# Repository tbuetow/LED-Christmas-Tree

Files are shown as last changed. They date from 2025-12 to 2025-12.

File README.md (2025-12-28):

# 🎄RGB LED Christmas Trees! <!-- omit in toc -->

- [How We Made These](#how-we-made-these)
  - [3D Printed Parts](#3d-printed-parts)
    - [Base](#base)
    - [Trees](#trees)
    - [PCB Fixture](#pcb-fixture)
  - [Circuit Boards](#circuit-boards)
  - [Software](#software)
  - [Putting it all together](#putting-it-all-together)
- [Building your own effects](#building-your-own-effects)
  - [Prerequisites](#prerequisites)
  - [VSCode / PlatformIO](#vscode--platformio)
  - [Writing effects](#writing-effects)

Each year, I make a small holiday bauble for teachers, family, and friends. Usually my wife and I come up with an idea around Thanksgiving and then panic for three weeks to deliver something by the last day of school for the holidays.

This year we chose to revisit something we made 7 years ago, but improve on it, building on some of my more recent projects with addressable RGB LEDs and better tools like my multiple extruder 3D printer and solder reflow oven.

The concept is a clear thin 3D printed tree on top of a 3D printed base that powers LEDs inside of it. 7 years ago, this was a pair of AA batteries, a single discrete color changing LED, and a power switch. You could also run it off of a 5V supply via micro-USB. Times have changed now! I had a few simple improvements I wanted to make.

- USB-C with proper support for all USB-C power supplies. I chose to drop batteries just due to cost.
- A ring of addressable RGB LEDs instead of a single unmodifiable color changing LED.
- The ability to change the LED color effects, and provide many included options.
- Multiple color printing to make it more beautiful.
- Under $10 and very easy to manufacture, since we want to make 30-40 of these.
- Document the process to share with others and allow those who are inclined to write their own color effects.

# How We Made These
## 3D Printed Parts
### Base
I designed the base and all other fixtures and accessories (except for the trees) in Autodesk Fusion.

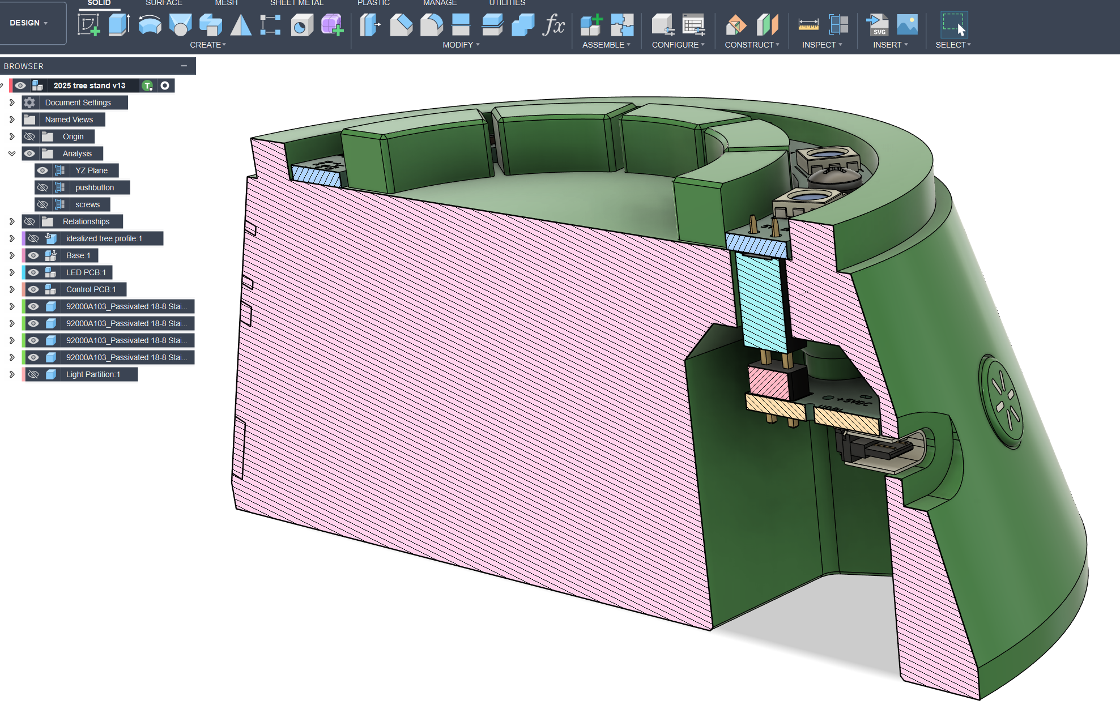
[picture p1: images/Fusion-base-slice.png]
Fusion screenshot


You can download the full model from my [Fusion account](https://a360.co/4piaKZ3) if you want to make modifications yourself. Fusion is free for personal use; get it [here](https://www.autodesk.com/products/fusion-360/overview).

The most likely thing you will want to modify is the embedded text. Just edit the text sketch on the Base component. I've removed the bottom row for the shared model. If you want to add one, add a text to the lower curved line. You will then want to edit the emboss and boundary fill operations immediately after the text in order to ensure the new text is properly embossed.

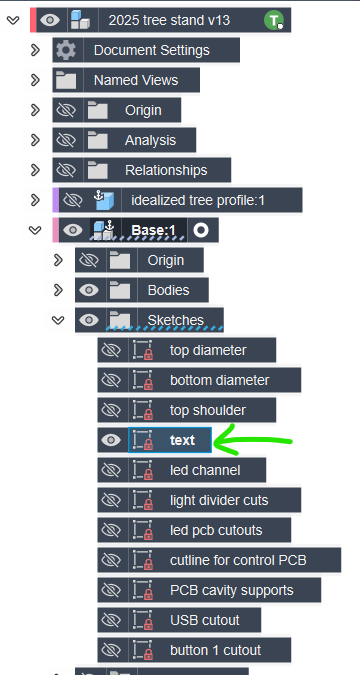
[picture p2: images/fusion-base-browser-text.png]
Fusion Browser Tree View, highlighting a sketch called text


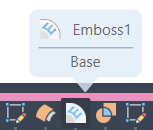
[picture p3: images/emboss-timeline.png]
Fusion timeline, highlighting the text sketch and the emboss and boundary fill operations


Printing was done on my Prusa XL and Core One.
I started by testing color combinations:

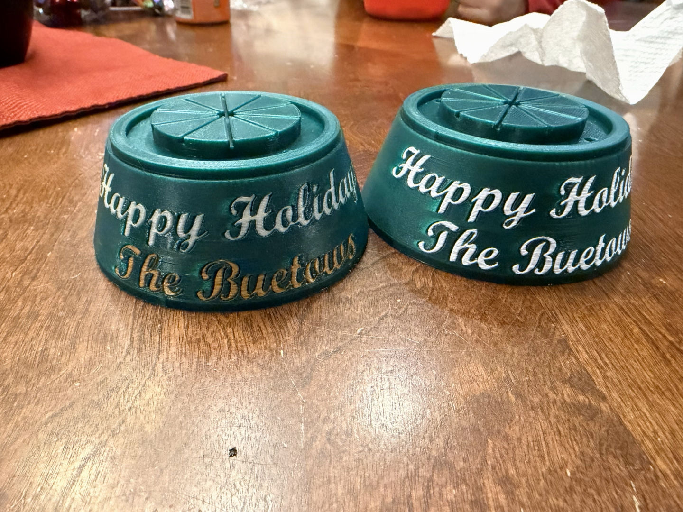
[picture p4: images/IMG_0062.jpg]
Tree base in green with text colors for text


Once done, I was able to begin producing them multiples at a time:

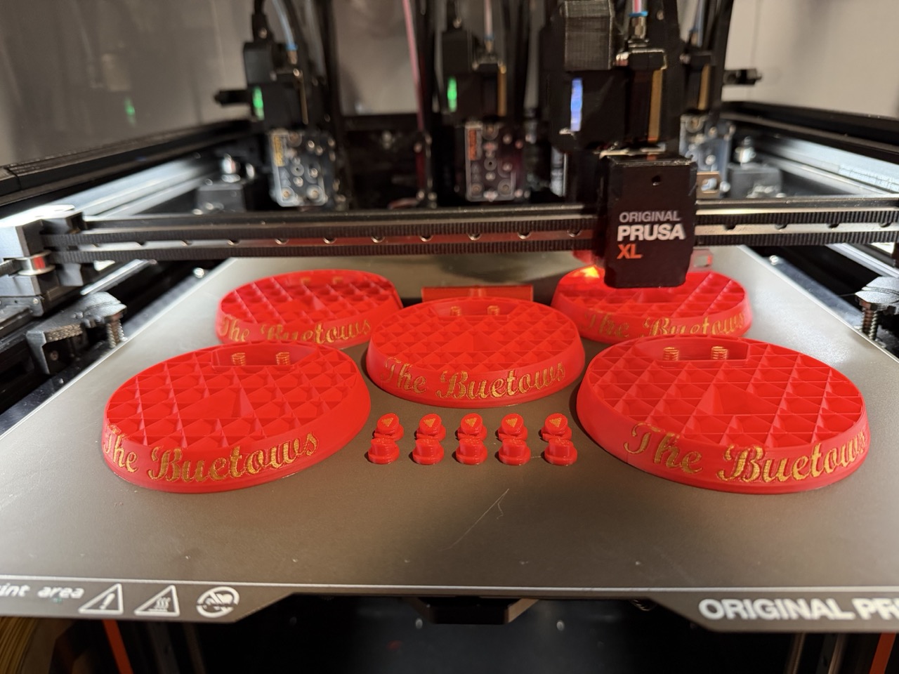
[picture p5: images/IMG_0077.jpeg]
Tree base printing in progress


The light dividers and trees were printed on the Core One. Lots of time starting the next print!

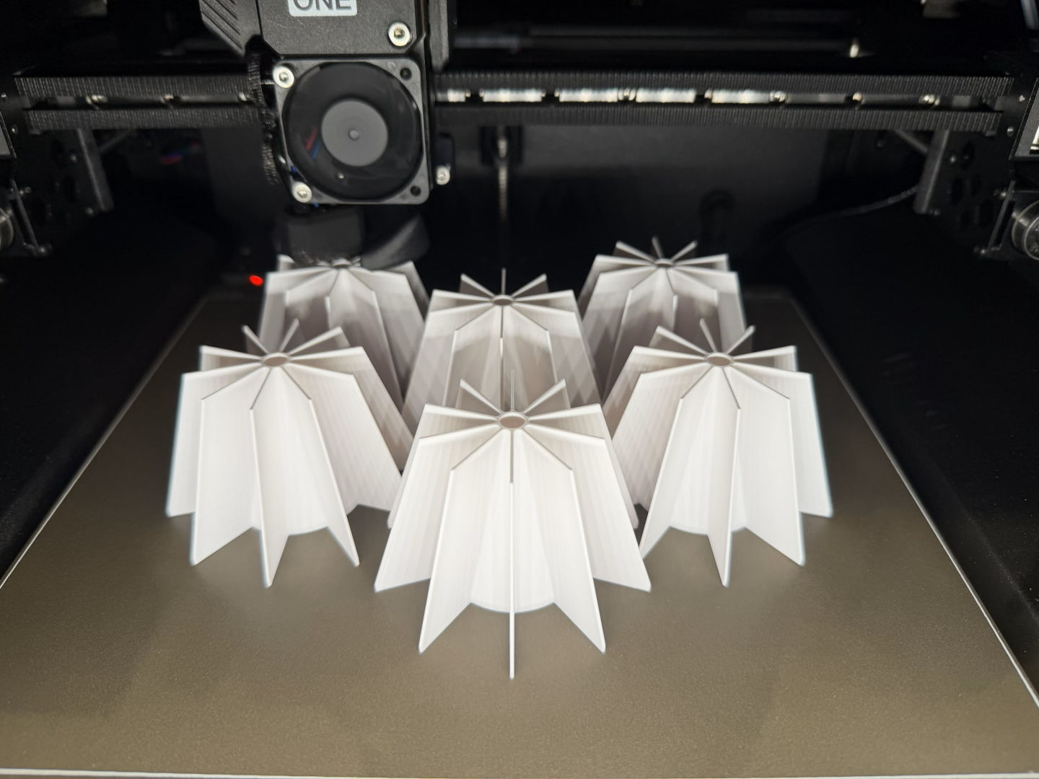
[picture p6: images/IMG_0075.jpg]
Plastic dividers printing


### Trees
I used tree designs that would print well in vase mode since I wanted them to be transparent. See [Trees](hw/Trees/) for more information.

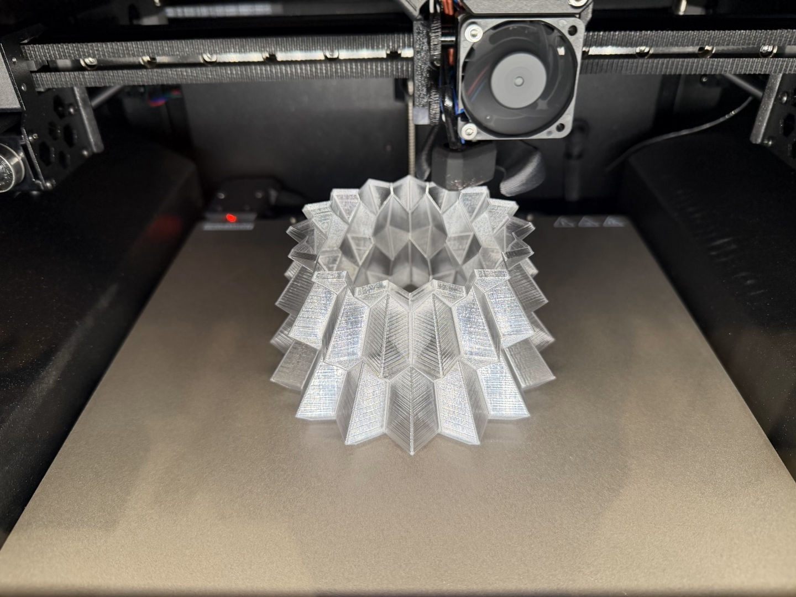
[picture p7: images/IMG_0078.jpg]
Clear tree printing in vase mode


Eventually the trees multiplied. Storing things became a challenge!

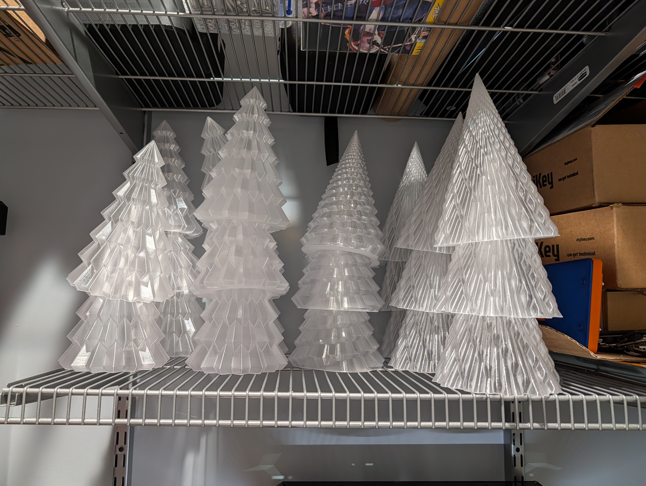
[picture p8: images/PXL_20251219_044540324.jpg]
Lots of printed trees


### PCB Fixture
I designed and printed a fixture to help with soldering as well, available in [Fixtures](/hw/Fixtures/). The fixture was printed in carbon-fiber reinforced PETG, to help the print maintain flatness. Any similar material, maybe even plain PLA, may be fine. The holes on the left are for M4 heat set inserts, used to hold the clamp in place.

<!-- Insert Fixture Picture here -->

## Circuit Boards
The circuit boards were designed in KiCAD. Thanks to the power of modern microprocessors and addressable LEDs, the circuit is quite simple.
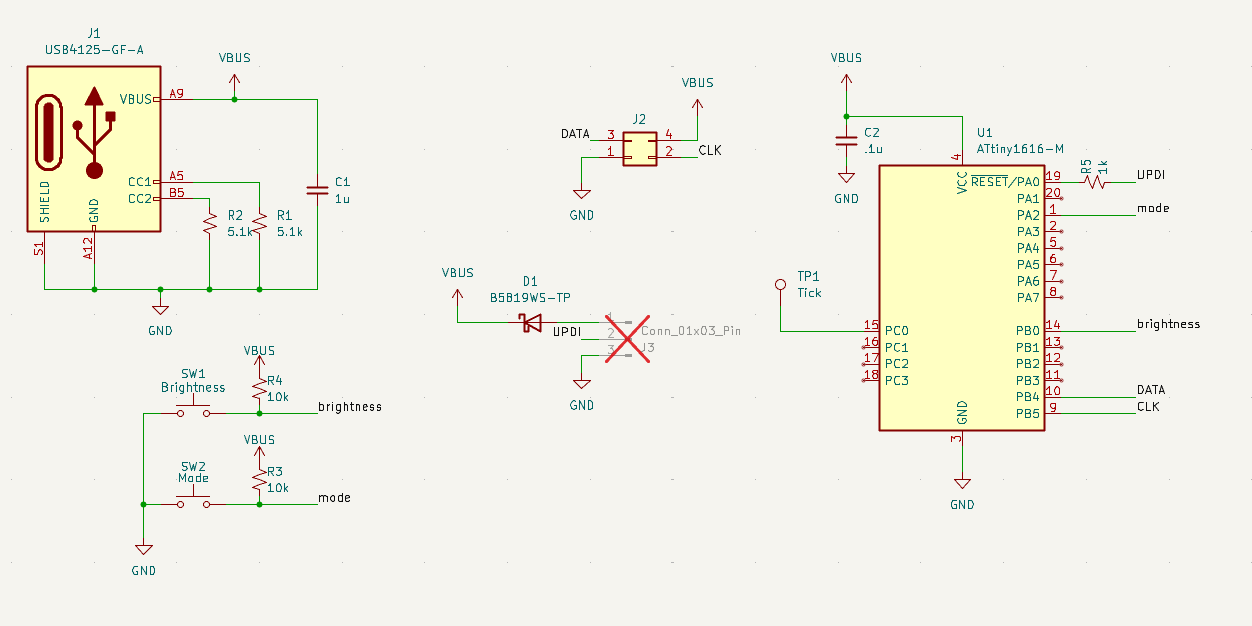
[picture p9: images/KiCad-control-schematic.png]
KiCad Electrical Schematic


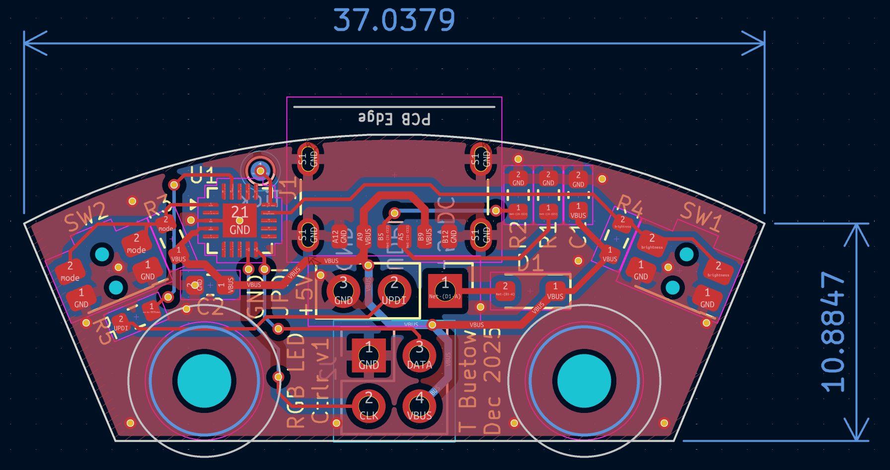
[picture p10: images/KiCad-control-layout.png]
KiCad Electrical Layout


The control board is **very** small, just 37mm (under 1.5") across. This is in part because I can get the new(er) Microchip ATTiny1616 in a VQFN package. These are ordered as bare PCBs and I use solder paste and stencils to set components and then reflow them in my solder oven. Hand soldering these would not be possible! The microprocessor has a 0.4mm (1/64") pitch, which is really tiny! It would be better to switch to slightly larger components and change the microprocessor out for one in a SOIC package or similar if you don't have a reflow oven.

However, I do have one!

You start by spreading solder paste over a thin steel stencil onto the PCB.
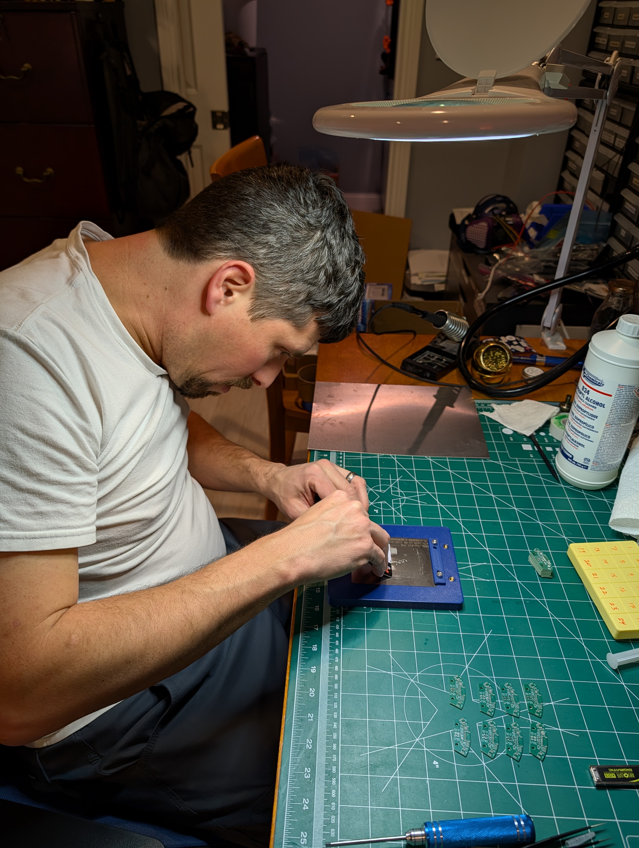
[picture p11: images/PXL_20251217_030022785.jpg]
Applying solder paste to a stencil on a fixture


Then components are carefully placed onto the board, sitting on the solder paste.
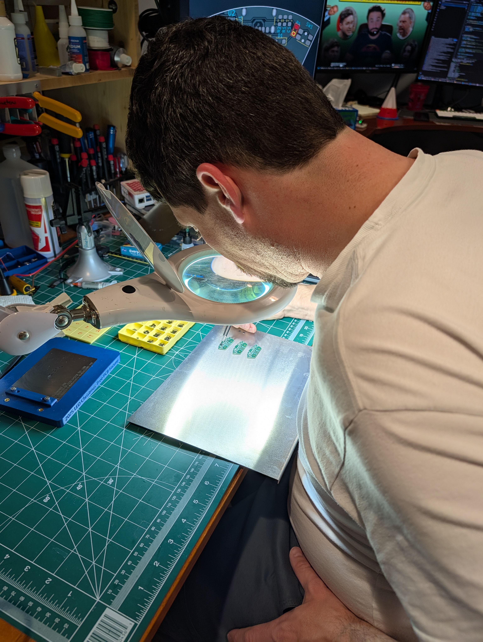
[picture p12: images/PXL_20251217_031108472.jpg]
Looking through a magnifier while placing components on a PCB.


Then they are baked in my reflow oven, converted from a cheap toaster oven. 30 seconds at 473F should do nicely!
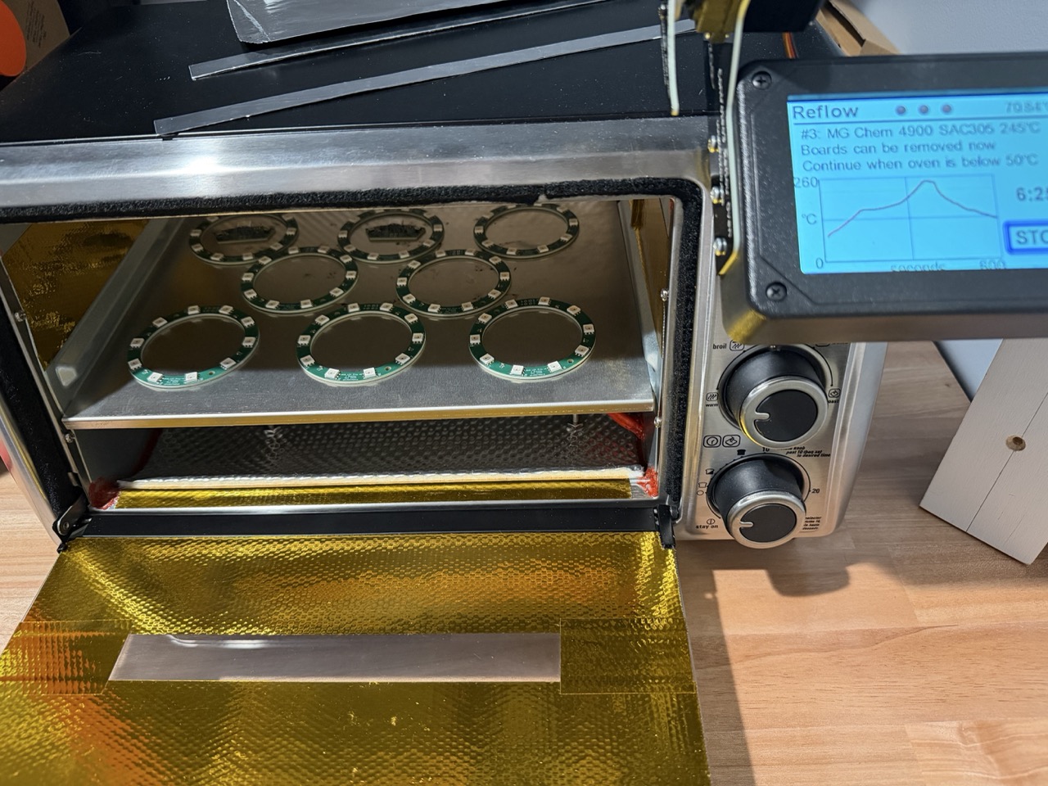
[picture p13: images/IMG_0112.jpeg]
Circuit boards fresh from the reflow oven


Once done, the fixture was used again to do the hand soldering part to add the header pins to connect the two boards together.
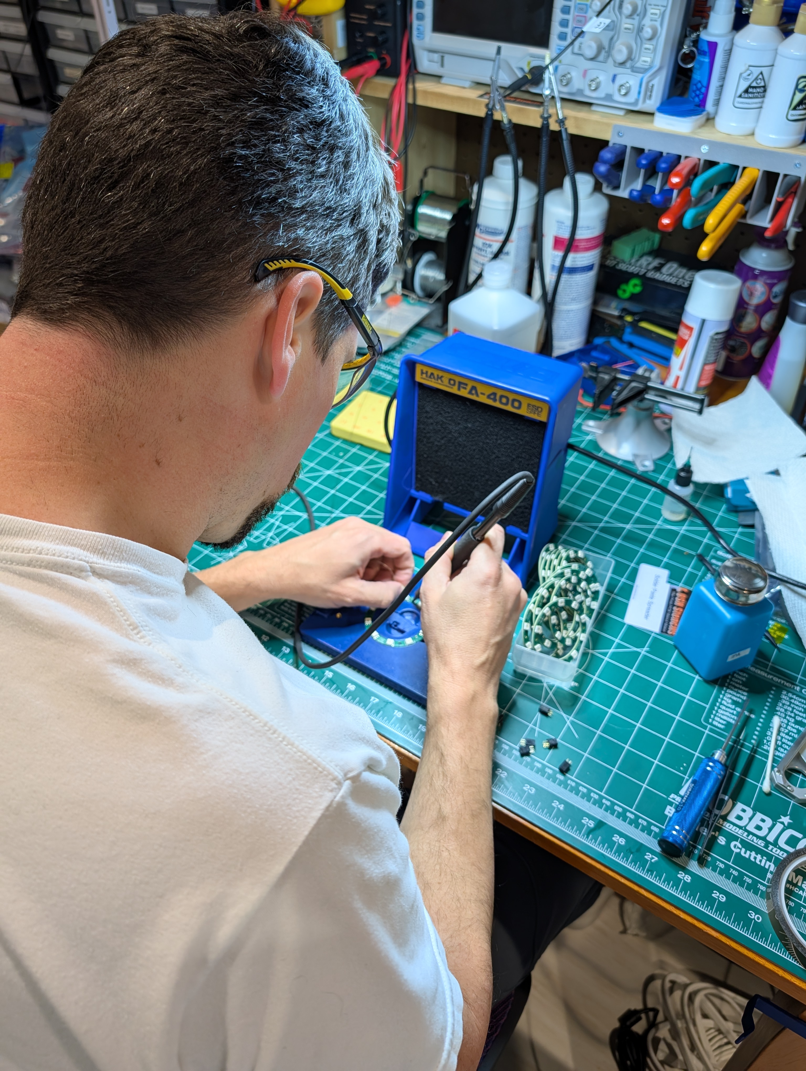
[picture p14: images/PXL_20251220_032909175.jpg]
Hand soldering parts onto a PCB


## Software
I used PlatformIO in VSCode as my IDE to program the microcontrollers. This works well and makes it easy to import the Arduino framework and FastLED library for quick access to easy-to-use functions and tools.

The bulk of the code came from another project I made where I had LED name plates that were edge-lit with RGB LEDs. I just added a few additional effects. [main.cpp](src/main.cpp) is where the effect implementations live and is available in the [src](src/) folder. Also there is [config.h](src/config.h) that contains all the "user" changeable parameters that I broke out. This made it easy to tune the effects to get them to look the way I wanted.

One of the new techniques I made is called Holiday Noise. It uses Perlin Noise to shift between red, green, and white colors. You can learn more about the 2D Perlin Noise in FastLED (one of the dimensions is time!) the same way I did by watching [this YouTube video by Scott Marley](https://youtu.be/7Dhh0IMSI4Q?t=266).

## Putting it all together
The base is designed to print with only minimal support (see the 3mf core one or XL files in [Base Hardware](/hw/Base/)).

Step 1 was to place the buttons and the control board in the bottom. The base was designed to allow it to slide into position, locking the buttons in place. M2.5 screws were used to hold the PCB in place.
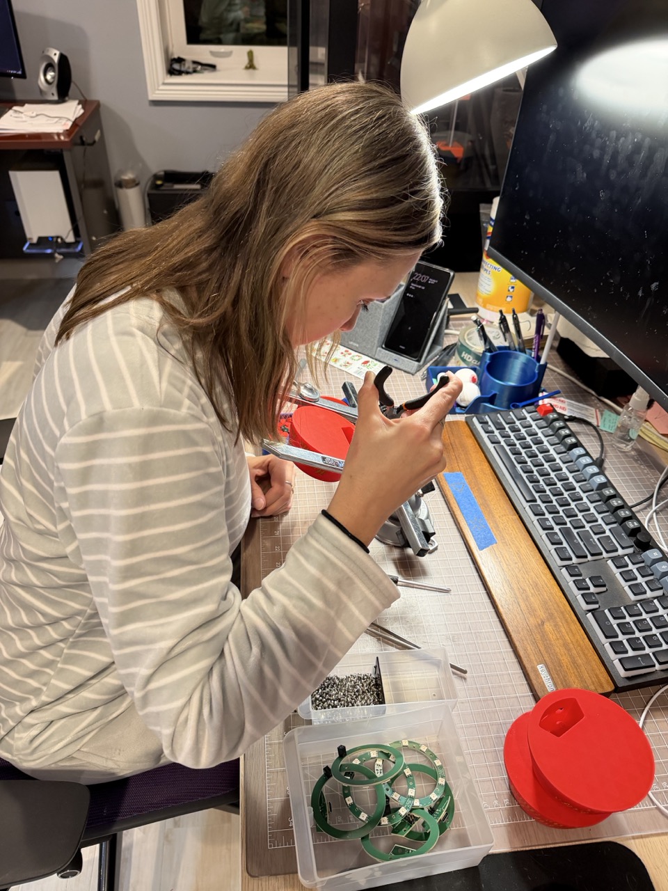
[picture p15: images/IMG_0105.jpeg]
Installing buttons and control board into base


Then the LED ring simply installed on the top with two more screws. The header pins lined up precisely to provide the electrical connections between the two boards.
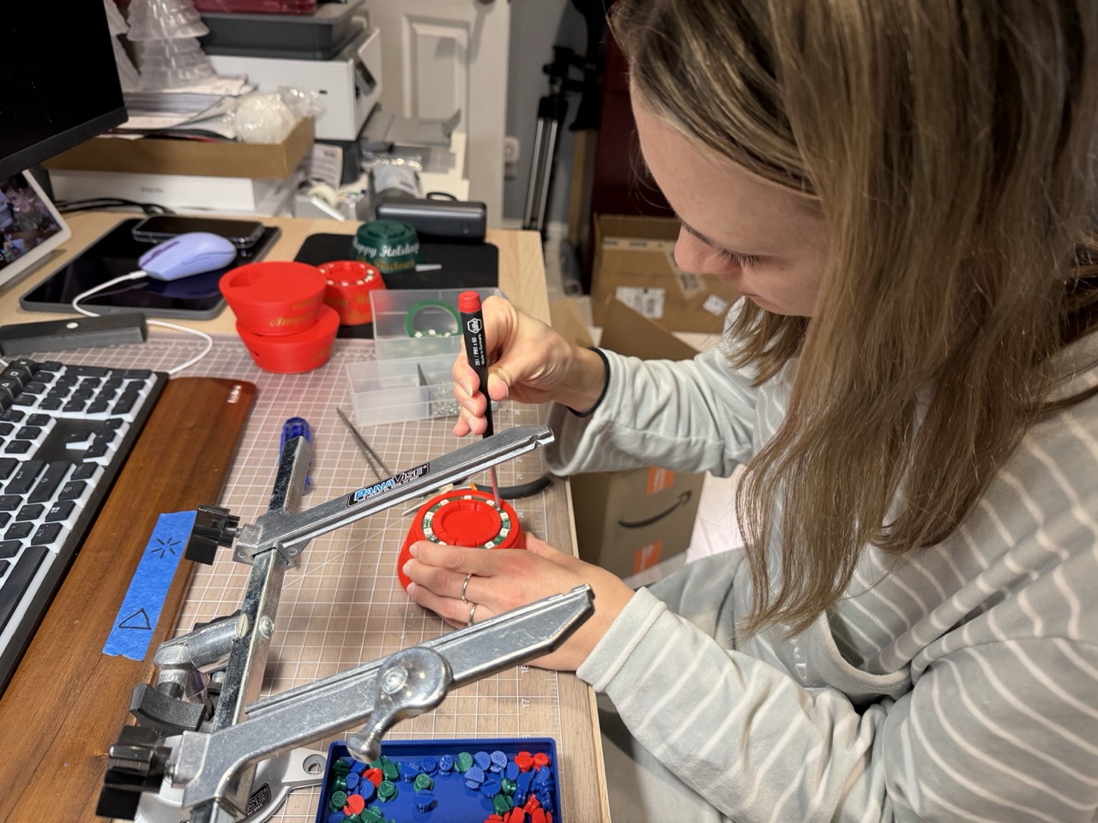
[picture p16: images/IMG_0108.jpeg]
Screwing LED PCB onto base


Finished!
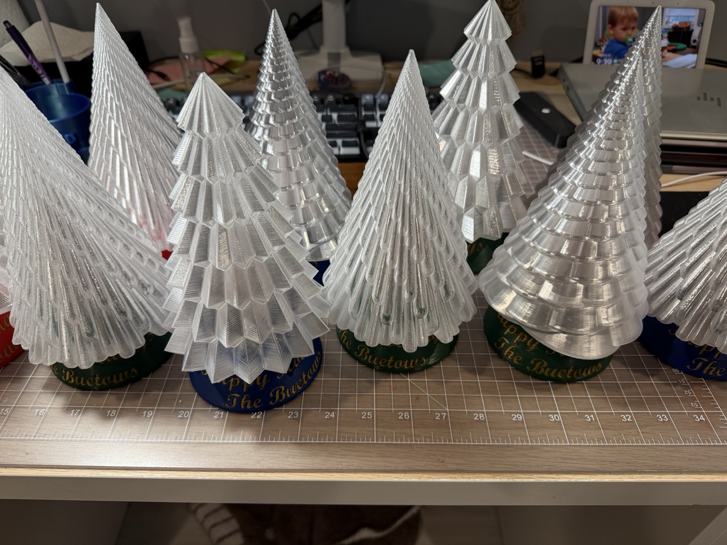
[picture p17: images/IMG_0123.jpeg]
Large collection of completed trees


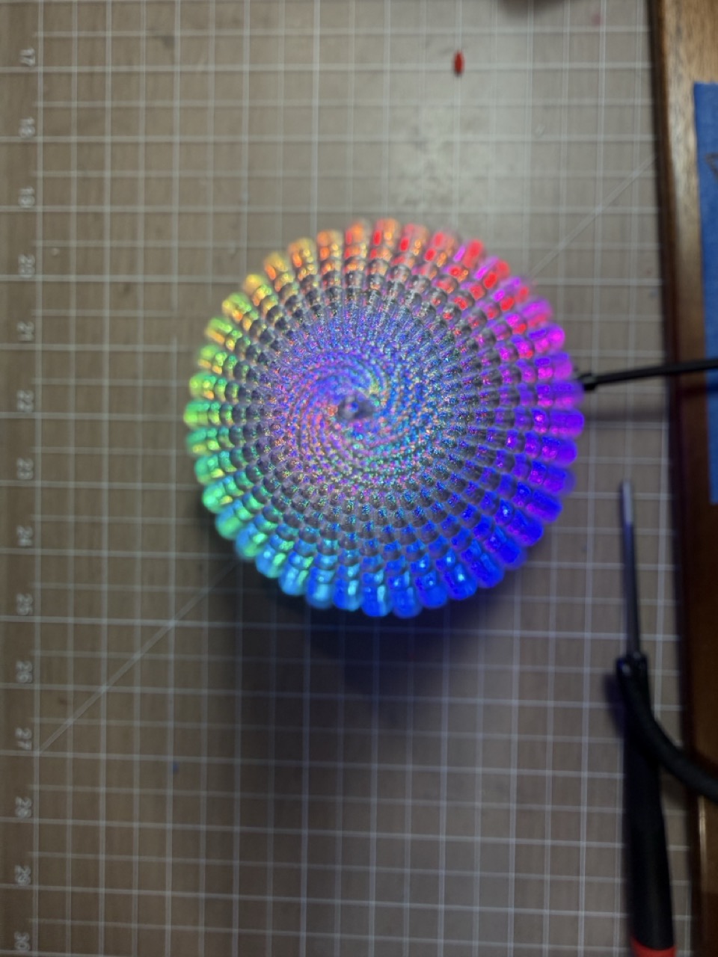
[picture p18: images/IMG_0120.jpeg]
Top down tree with rainbow effect


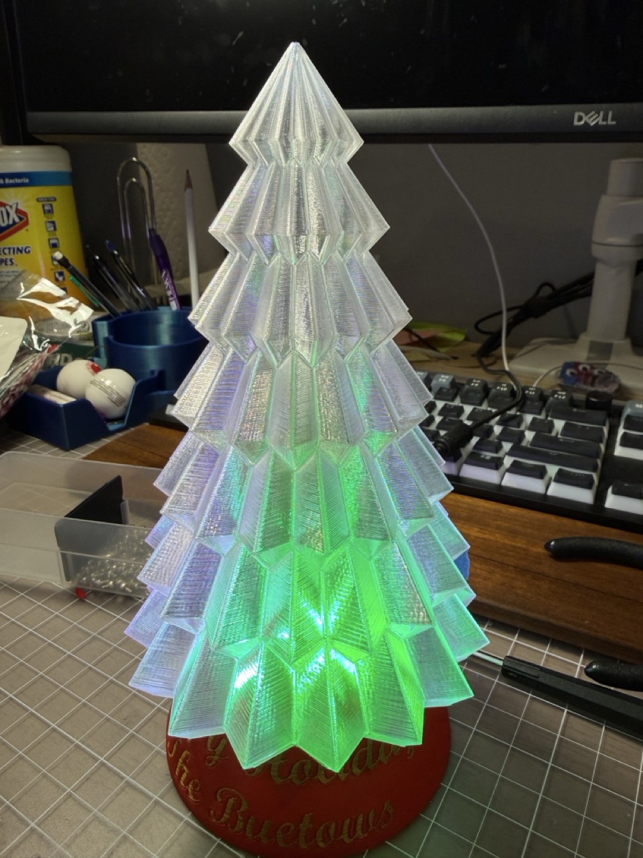
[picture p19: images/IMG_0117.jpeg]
Tree light up with green carousel effect


# Building your own effects
## Prerequisites
- **Programmer:** You will need a UPDI programmer. You can make one from a USB to serial adapter by just connecting USB Serial RX to the UPDI pin, and then the USB Serial TX to RX with a 1kΩ Resistor. Or you can buy something cheap like the [Adafruit UPDI Friend](https://www.adafruit.com/product/5879) or the High Voltage version too.

- **Jumper wires:** If I installed the 3 male header pins on your board, you will need to adapt the Programmer to 3 0.1" female connectors. The Adafruit one will give you 3 male header pins, so you will need 3 female to female jumpers. Grab [these](https://www.adafruit.com/product/1950) from Adafruit if you are already buying the UPDI Friend, or they are also in [this pack](https://www.amazon.com/Elegoo-EL-CP-004-Multicolored-Breadboard-arduino/dp/B01EV70C78) from Amazon. 

  Programming without the male header is still possible, I just press the programming pins into the holes and push them sideways to ensure electrical contact.

- **VSCode:** You will need an Integrated Development Environment. I use [VSCode](https://code.visualstudio.com/). Within VSCode, you will need the PlatformIO extension. Go to the Extensions tab and search for it within VSCode or grab it from the [extensions marketplace](https://marketplace.visualstudio.com/items?itemName=platformio.platformio-ide).

- **Git:** You probably want to get the [git version control system](https://git-scm.com/) to make it easy to get access to the code. This step is technically optional, but will allow you to undo changes you make at any time.

## VSCode / PlatformIO
1) Install the PlatformIO extension in VSCode. After it finishes, reload VSCode so it can add toolchains the first time you open the project.
1) Clone or download this repo. If you have git, use `git clone` from a terminal. Otherwise use the green "Code" button on GitHub to download a zip, then unzip it somewhere easy to find.
1) In VSCode, go to `File -> Open Folder...` and pick the project root. PlatformIO should notice `platformio.ini` and prompt to install anything it needs—let it run to completion.
1) In the left sidebar, open `platformio.ini` to confirm the `ATtiny1616` environment is selected. Click `src/main.cpp` to browse the effects code and `src/config.h` to tweak tunable values.
1) Hook up your UPDI programmer: UPDI to the single UPDI pin, GND to GND, and 5V to VCC on the control board. I keep the base on its back so the pins are easy to reach.
1) Click the PlatformIO checkmark (Build) to make sure everything compiles, then use the right-facing arrow (Upload using Programmer) to flash the board.

## Writing effects
To write your own effects, you'll need to touch at least two files, ideally 3.

The effects are implemented in [main.cpp](/src/main.cpp). That is where you will do the bulk of the work. Add a case statement to the switch conditional in the loop() function. 

However, the system won't know your effect exists until you add it to the list of states. Go to the [state.h](/src/state.h) file and add it to the Mode class. This class defines the order the effects rotate through when you push the next button on the base.

If you wish to make tuneable variables, it's best practice to add them in [config.h](/src/config.h) but I won't judge you if you just hard code them all in your implementation code.

My effects make use of the `EVERY_N_MILLIS()` timer capabilities in FastLED extensively. This avoids a whole bunch of timer checking code since the people who wrote FastLED are way better at this stuff than I am.

Hopefully that's enough to get you started on your own. Don't be afraid to feed main.cpp to a chatbot and ask it to help you add new effects in the right format. It's a great way to experiment at first. Have fun!

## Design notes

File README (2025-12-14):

# 🎄RGB LED Christmas Trees!

Each year, I make a small holiday bauble for teachers, family, and friends. Usually my wife and I come up with an idea around Thanksgiving and then panic for three weeks to deliver something by the last day of school for the holidays.

This year we chose to revisit something we made 7 years ago, but improve on it, building on some of my more recent projects with addressable RGB LEDs and better tools like my multiple extruder 3D printer and solder reflow oven.

The concept is a clear thin 3D printed tree on top of a 3D printed base that powers LEDs inside of it. 7 years ago, this was a pair of AA batteries, a single discrete color changing LED, and a power switch. You could also run it off of a 5V supply via micro-USB. Times have changed now! I had a few simple improvements I wanted to make.

- USB-C with proper support for all USB-C power supplies. I chose to drop batteries just due to cost.
- A ring of addressable RGB LEDs instead of a single unmodifiable color changing LED.
- The ability to change the LED color effects, and provide many included options.
- Multiple color printing to make it more beautiful.
- Under $10 and very easy to manufacture, since we want to make 30-40 of these.
- Document the process to share with others and allow those who are inclined to write their one color effects.

## 3D Printed Parts
I designed the base and all other fixtures and accessories, except for the trees in Autodesk Fusion.
Fusion screenshot

Printing was done on my Prusa XL and Core One.
I started by testing color combinations:
Tree base in green with text colors for text

Once done, I was able to begin producing them multiples at a time:
Tree base printing in progress

The light dividers and trees were printed on the Core One. Lots of time starting the next print!
Clear tree printing in vase mode
Plastic dividers printing

## Circuit Boards
The circuit boards were designed in KiCAD. Thanks to the power of modern microprocessors and addressable LEDs, the circuit is quite simple.
KiCad Electrical Schematic
KiCad Electrical Layout

The control board is **very** small, just 37mm (under 1.5") across. This is in part because I can get the new(er) Microchip ATTiny1616 in a QFN packaged. These are ordered as bare PCBs and I use solder paste and stencils to set components and then reflow them in my solder oven. I would not recommend hand soldering these unless you are very skilled. It would be better to switch to slightly larger components and change the microprocessor out for one in a SOIC package or similar.

<Insert solder oven photo here>

## Software
I used PlatformIO in VSCode as my IDE to program the microcontrollers. This works well and makes it easy to import the Arduino framework and FastLED library for quick access to easy-to-use functions and tools.

The bulk of the code came from another project I made where I had LED name plates that were edge-lit with RGB LEDs. I just added a few additional effects. [main.cpp](src/main.cpp) is available in the [src](src/) folder.

# Building your own effects
## Prerequisites

## VSCode / PlatformIO

## Writing effects

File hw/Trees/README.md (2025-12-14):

# Vase Trees
A Selection of trees that I liked to print in vase mode and put on top of the LED Bases.

The spiral trees are courtesy of [Triple G Workshop](https://www.printables.com/model/655419-ultimate-vase-mode-christmas-tree-collection/files).

The pointy tree is courtesy of [SASSy Design](https://www.printables.com/model/684498-sassy-christmas-tree-vase-mode-geometrical-design).

## Project 3MF files
The 3MF files here are preconfigured for printing, including the hole to fit over the LED base, as described below.

All trees in the project have some form of license or copyright that I do not control unless stated otherwise. Individual trees have their associated licenses detailed in their respective folders.

Unfortunately, some of these licenses do not allow me to host copies or even derivative works, so they are not included here. Please see the attribution documents and links above to obtain them.

## How to Slice
### Import model
Bring the model into your slicer and resize it to be 120mm in diameter (set X and Y to be the same) and 180mm in height. You may need to unlock sizing constraints

### Add hole to fit over LED Base
Add a negative cylinder shape to the tree in your slicer.

Make it 75.1mm in diameter and 1mm tall.

Make sure it is placed on the bed and centered with reference to the tree model

### Slicer settings
Set the slicer to vase mode

The gcode preview should show an open hole at the bottom, with an inner wall that is 1mm high.

### Optional point fix
These trees will all end up with very sharp tips. I recommend using your slicer to cut off the top 2mm.

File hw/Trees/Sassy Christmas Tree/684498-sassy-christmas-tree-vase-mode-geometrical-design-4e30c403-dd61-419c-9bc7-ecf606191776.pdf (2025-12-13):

# Sassy Christmas Tree - Vase mode -

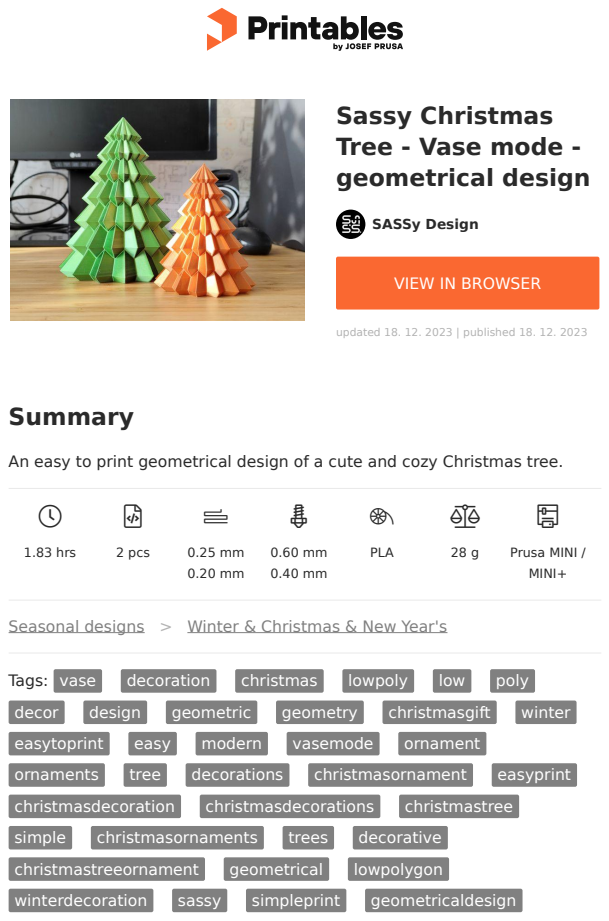
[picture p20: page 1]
1.83 hrs; 2 pcs; PLA; Prusa MINI /; MINI+; Summary; Seasonal designs; Winter & Christmas & New Year's; Tags: vase; decoration; christmas; lowpoly; low; poly; decor; design; geometric; geometry; christmasgift; winter; easytoprint; easy; modern; vasemode; ornament; ornaments; tree; decorations; christmasornament; easyprint; christmasdecoration; christmasdecorations; christmastree; simple; christmasornaments; trees; decorative; christmastreeornament; geometrical; lowpolygon; winterdecoration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

VIEW IN BROWSER (https://printables.com/model/684498-sassy-christmas-tree-vase-mode-geometrical-design)

An easy to print geometrical design of a cute and cozy Christmas tree.

# Model files

# Print files

moderndesign | geometricdesign | 2023 | vasemodeprinting
sassydesign | winterdecorations

An easy to print geometrical design of a cute and cozy Christmas tree.

### Print information:

Recommended vase mode or semi-vasemode settings (0% infill, 0 top

layers, 4 or 5 bottom layers, 2 or 3 outer perimeters - for a stronger

print)

Recommended using a lower layer hight (0.15/0.2mm) for better

results in details

Prints very good in any filament

The model is scalable to your liking

Happy printing!

And a Merry Christmas to all of you!

h PLA | k 0.60 mm | f 0.25 mm | 1.83 hrs | 28 g | d Prusa MK4

•

•

•

•

sassy-christmas-tree_vase-mode.stl

sassy-christmas-tree.stl

sassy-christmas-tree__06n_025mm_pla_mk4is_1h50m.gcode

h PLA | k 0.40 mm | f 0.20 mm | 2.23 hrs | 20 g | d Prusa MINI / MINI+

# License

This work is licensed under a Standard Digital File Licence.

Digital files have a strict non-commercial, personal use only license.

You shall not share, sub-license, sell, rent, host, transfer, or distribute in

any way the digital file or 3D printed versions of this object, nor any other

derivative work of this object in its digital or physical format (including

remixes of this object).

You can not host these files on other digital platforms, web stores or cloud

repositories.

The objects may not be used in any way whatsoever in which you charge

money, collect fees.

✖ | No sharing or redistributing in any way of the 3D files or derivatives
✖ | No remixing
✖ | Non-commercial Use (only for personal use) sassy-christmas-tree__04n_02mm_pla_mini_2h14m.gcode

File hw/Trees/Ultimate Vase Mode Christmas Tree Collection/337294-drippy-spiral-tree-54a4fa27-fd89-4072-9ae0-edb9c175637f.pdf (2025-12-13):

## Drippy Spiral Tree

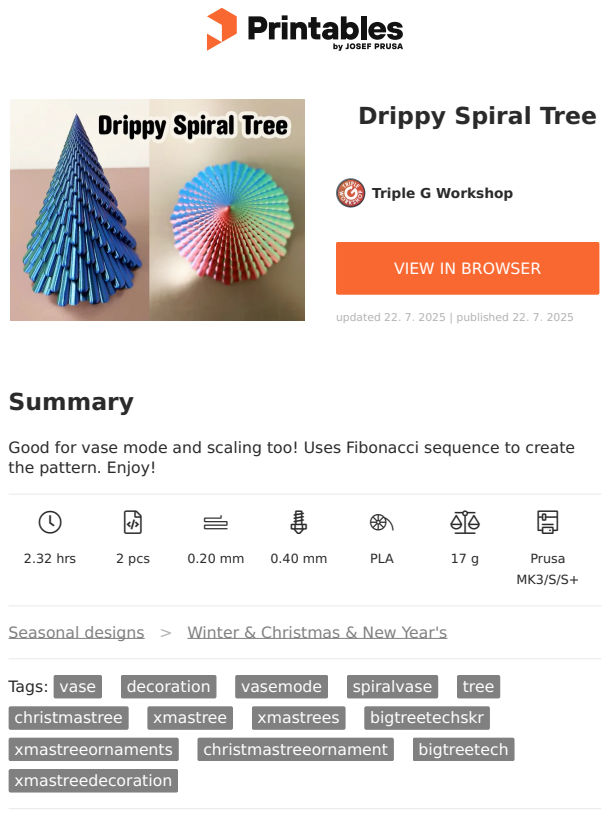
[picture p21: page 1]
2.32 hrs; 2 pcs; PLA; Prusa MK3/S/S+; Summary; Tags:; vase; decoration; vasemode; spiralvase; tree; christmastree; xmastree; xmastrees; bigtreetechskr; xmastreeornaments; christmastreeornament; bigtreetech; xmastreedecoration; Triple G Workshop; updated 22. 7. 2025 | published 22. 7. 2025

VIEW IN BROWSER (https://printables.com/model/337294-drippy-spiral-tree)

Good for vase mode and scaling too! Uses Fibonacci sequence to create
the pattern. Enjoy!

Seasonal designs (https://printables.com/model?categoryId=65) > Winter & Christmas & New Year's (https://printables.com/model?categoryId=70)

## Model files

## Print files

h PLA k 0.40 mm f 0.20 mm 2.32 hrs 17 g d Prusa MK3/S/S+

h PLA k 0.40 mm f 0.20 mm 0.74 hrs 5 g d Prusa MK3/S/S+

## License

This work is licensed under a
Creative Commons (4.0 International License)

Attribution—Noncommercial—Share Alike (http://creativecommons.org/licenses/by-nc-sa/4.0/)

✖ | Sharing without ATTRIBUTION
✔ | Remix Culture allowed
✖ | Commercial Use
✖ | Free Cultural Works
✖ | Meets Open Definition

drippy-spiral-tree.3mf

drippy-spiral-tree.stl

drippy-spiral-tree-solid_02mm_pla_mk3s_2h19m.gcode

drippy-spiral-tree-_vase-mode_-02mm_pla_mk3s_45m.gcode

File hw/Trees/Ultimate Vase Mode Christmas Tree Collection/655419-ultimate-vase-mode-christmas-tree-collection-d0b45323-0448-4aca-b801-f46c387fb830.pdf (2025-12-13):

## ⍋ Ultimate Vase Mode Christmas

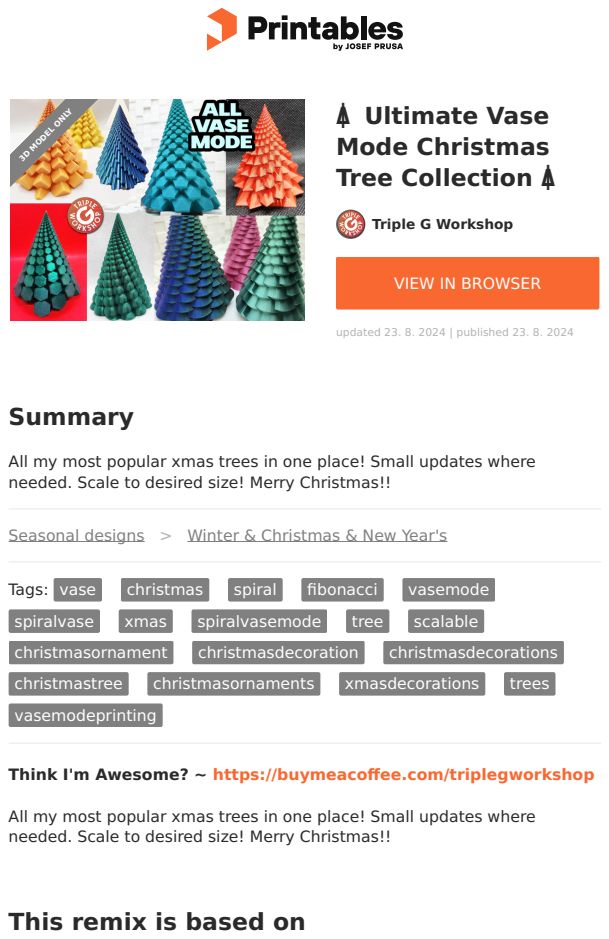
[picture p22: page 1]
Summary; Tags:; vase; christmas; spiral; fibonacci; vasemode; spiralvase; xmas; spiralvasemode; tree; scalable; christmasornament; christmasdecoration; christmasdecorations; christmastree; christmasornaments; xmasdecorations; trees; vasemodeprinting; Triple G Workshop; Tree Collection ⍋; updated 23. 8. 2024 | published 23. 8. 2024; 3D MODEL ONLY

VIEW IN BROWSER (https://printables.com/model/655419-ultimate-vase-mode-christmas-tree-collection)

All my most popular xmas trees in one place! Small updates where
needed. Scale to desired size! Merry Christmas!!

Seasonal designs (https://printables.com/model?categoryId=65) > Winter & Christmas & New Year's (https://printables.com/model?categoryId=70)

Think I'm Awesome? ~ https://buymeacoffee.com/triplegworkshop (https://t.co/ddvOmmeLwR)

This remix is based on

Fibonacci Spiral Trees No Supports (https://printables.com/model/334911-fibonacci-spiral-trees-no-supports) by Triple G Workshop (https://printables.com/@TripleGWorkshop)

⬡ Crystal-mas Tree Vase Mode ⬡ (https://printables.com/model/337015-crystal-mas-tree-vase-mode) by Triple G Workshop (https://printables.com/@TripleGWorkshop)

Sugar Cube Tree ◇ Vase Mode (https://printables.com/model/456678-sugar-cube-tree-vase-mode) by Triple G Workshop (https://printables.com/@TripleGWorkshop)

Fibonacci Spiral Trees ⍋ Vase Mode V2 (https://printables.com/model/632685-fibonacci-spiral-trees-vase-mode-v2) by Triple G Workshop (https://printables.com/@TripleGWorkshop)

⍋ Crystal Tree & Spiral Vase ⍋ (https://printables.com/model/625815-crystal-tree-spiral-vase) by Triple G Workshop (https://printables.com/@TripleGWorkshop)

Tree Full of Stars ✫ Vase Mode (https://printables.com/model/459173-tree-full-of-stars-vase-mode) by Triple G Workshop (https://printables.com/@TripleGWorkshop)

Vase Mode Xmas Tree ☆ (https://printables.com/model/307157-vase-mode-xmas-tree)
by Triple G Workshop (https://printables.com/@TripleGWorkshop)

Drippy Spiral Tree (https://printables.com/model/337294-drippy-spiral-tree)
by Triple G Workshop (https://printables.com/@TripleGWorkshop)

⍟ Tree of Spheres - Solid or vase mode ⍟ (https://printables.com/model/337759-tree-of-spheres-solid-or-vase-mode) by Triple G Workshop (https://printables.com/@TripleGWorkshop)

Xmas Tree Vase Mode Caddy (https://printables.com/model/452819-xmas-tree-vase-mode-caddy)
by Triple G Workshop (https://printables.com/@TripleGWorkshop)

## Model files

- All Models HERE!

ultimate-vase-mode-christmas-tree-collection.3mf

4-sided-fibonacci-spiral-tree.stl

6-sided-fibonacci-spiral-tree.stl

10-sided-fibonacci-spiral-tree.stl

fibonacci-spiral-trees-v2-1.stl

fibonacci-spiral-trees-v2-2.stl

fibonacci-spiral-trees-v2-3.stl

crystal-tree-vase-mode-tall.stl

crystal-mastreevasemode.stl

- this model may have tiny gaps inside the stars, it experimental

## License

This work is licensed under a
Creative Commons (4.0 International License)

Attribution-ShareAlike (http://creativecommons.org/licenses/by-sa/4.0/)

✖ | Sharing without ATTRIBUTION diamond-xmas-tree-vase-mode.stl

tree-of-spheres-vase-mode.stl

sugar-cube-tree-vase-mode.stl

christmas-tree-with-star-vase-mode.stl

xmas-tree-caddy-vase-mode.stl

spiral-tree-full-of-stars.stl

drippy-spiral-tree.stl

✔ | Remix Culture allowed
✔ | Commercial Use
✔ | Free Cultural Works
✔ | Meets Open Definition

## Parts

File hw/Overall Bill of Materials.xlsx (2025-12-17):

 | Total units: | 30
Part | Description | Manufacturer | Man PN | Ref Des | Vendor | Unit QTY | Unit Cost | Assy Cost | # on hand | unit package qty | Purchase QTY | Ext Cost | Column1
Capacitor, 0.1u | CAP CER 0.1UF 16V X7R 0603 | KEMET | C0603C104K4RACTU | LED: C1,C2,C3,C4 Control: C2 | Digikey | 5 | $0.010 | $0.05 | 500 | 1 | 0 | $0.000
RGB LED | SK9822 or APA102C 5050 LED | Cocurve Official Store | 2251832309970313 | LED: D1,D2,D3,D4,D5,D6,D7,D8,D9,D10 | Aliexpress | 10 | $0.112 | $1.12 | 120 | 1 | 500 | $56.150
Board connector | CONN HDR 4POS 2X2 0.1 GOLD PCB | Sullins Connector Solutions | PPPC022LFBN-RC | LED: J1 | Digikey | 1 | $0.394 | $0.39 | 0 | 1 | 30 | $11.820
Capacitor, 1u | CAP CER 1UF 16V X7R 0603 | KEMET | C0603C105K4RACTU | Control: C1 | Digikey | 1 | $0.011 | $0.01 | 1000 | 1 | 0 | $0.000
Programmer protection diode | DIODE SCHOTTKY 40V 1A SOD323 | MCC (Micro Commercial Components) | B5819WS-TP | Control: D1 | Digikey | 1 | $0.087 | $0.09 | 90 | 1 | 0 | $0.000
USB C Connector | CONN RCPT TYPE C 6P SMD RA | GCT | USB4125-GF-A | Control: J1 | Digikey | 1 | $0.472 | $0.47 | 15 | 1 | 15 | $7.086
Board connector | CONN HEADER VERT 80POS 2ROW 2.54MM | Sullins Connector Solutions | PRPC040DAAN-RC | Control: J2 | Digikey | 0.05 | $1.030 | $0.05 | 0 | 1 | 2 | $2.060
UPDI connector | CONN HEADER VERT 3POS 2.54MM |  |  | Control: J3 | Digikey | 0 | $0.000 | $0.00 | 100 | 1 | 0 | $0.000
5.1k Resistor | RES 5.1K OHM 1% 1/10W 0603 | Stackpole Electronics Inc | RMCF0603FT5K10 | Control: R1,R2 | Digikey | 2 | $0.005 | $0.01 | 100 | 1 | 0 | $0.000
Jumper Resistor | RES 0 OHM JUMPER 1/10W 0603 | Stackpole Electronics Inc | RMCF0603ZT0R00 | Control: R5 | Digikey | 1 | $0.004 | $0.0043 | 250 | 1 | 0 | $0.000
10k Resistor | RES 10K OHM 1% 1/10W 0603 | Stackpole Electronics Inc | RMCF0603FT10K0 | Contro: R3,R4 | Digikey | 2 | $0.005 | $0.01 | 1000 | 1 | 0 | $0.000
Pushbutton Switches | SWITCH TACTILE SPST-NO 0.05A 12V | Panasonic Electronic Components | EVQ-P7L01P | Control: SW1,SW2 | Digikey | 2 | $0.241 | $0.48 | 0 | 1 | 60 | $14.448
microcontroller | IC MCU 8BIT 16KB FLASH 20VQFN | Microchip Technology | ATTINY1616-MNR | Control: U1 | Digikey | 1 | $0.820 | $0.82 | 0 | 1 | 30 | $24.600
PCB Screws | M2.5x0.45 4MM PAN HEAD PHILLIPS 18-8 STAINLESS | McMaster Carr | 92000A102 |  | mcmaster | 4 | $0.046 | $0.18 | 15 | 100 | 2 | $9.160
LED PCB | 64MM LED Ring with 10 addressable RGB LEDs |  | W949867ASM10 |  | PCBWay | 1 | $0.951 | $0.95 | 0 | 1 | 50 | $47.550
Control PCB | LED control PCB |  | W949867ASM8 |  | PCBWay | 1 | $0.447 | $0.45 | 0 | 1 | 50 | $22.330
PLA filament | Estimated filament for all base parts in kilograms | Prusa Research |  |  | Printed Solid | 0.0801 | $35.000 | $2.80 | 1 | 1 | 2 | $70.000
PETG filament | Estimated filament for tree in kilograms | Prusa Research |  |  | Printed Solid | 0.029 | $35.000 | $1.02 | 0 | 1 | 1 | $35.000
 |  |  |  |  |  |  |  | $0.00 |  |  | 0 | $0.000
 |  |  |  |  |  |  |  | $0.00 |  |  | 0 | $0.000
 |  |  |  |  |  |  |  | $0.00 |  |  | 0 | $0.000
 |  |  |  |  |  |  |  | $0.00 |  |  | 0 | $0.000
 |  |  |  |  |  |  |  | $0.00 |  |  | 0 | $0.000
 |  |  |  |  |  |  |  | $0.00 |  |  | 0 | $0.000
 |  |  |  |  |  |  |  | $0.00 |  |  | 0 | $0.000
 |  |  |  |  |  |  |  | $0.00 |  |  | 0 | $0.000
 |  |  |  |  |  |  |  | $0.00 |  |  | 0 | $0.000
Total |  |  |  |  |  |  |  | $8.91 |  |  |  | $300.204

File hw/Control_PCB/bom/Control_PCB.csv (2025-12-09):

Reference | Qty | Value | DNP | Exclude from BOM | Exclude from Board | Footprint | Datasheet
C1 | 1 | 1u |  |  |  | Capacitor_SMD:C_0603_1608Metric | ~
C2 | 1 | .1u |  |  |  | Capacitor_SMD:C_0603_1608Metric | ~
D1 | 1 | B5819WS-TP |  |  |  | Diode_SMD:D_SOD-323_HandSoldering | https://www.mccsemi.com/pdf/Products/B5817WS-B5819WS(SOD-323).PDF
J1 | 1 | USB4125-GF-A |  |  |  | Connector_USB:USB_C_Receptacle_GCT_USB4125-xx-x_6P_TopMnt_Horizontal | https://www.usb.org/sites/default/files/documents/usb_type-c.zip
J2 | 1 | PRPC040DAAN-RC |  |  |  | Connector_PinHeader_2.54mm:PinHeader_2x02_P2.54mm_Vertical | ~
J3 | 1 | Conn_01x03_Pin | DNP | Excluded from BOM |  | Connector_PinHeader_2.54mm:PinHeader_1x03_P2.54mm_Vertical | ~
R1,R2 | 2 | 5.1k |  |  |  | Resistor_SMD:R_0603_1608Metric | ~
R3,R4 | 2 | 10k |  |  |  | Resistor_SMD:R_0603_1608Metric | ~
R5 | 1 | 1k |  |  |  | Resistor_SMD:R_0603_1608Metric | ~
SW1 | 1 | Brightness |  |  |  | Button_Switch_SMD:SW_SPST_EVQP7C | ~
SW2 | 1 | Mode |  |  |  | Button_Switch_SMD:SW_SPST_EVQP7C | ~
TP1 | 1 | Tick |  |  |  | TestPoint:TestPoint_Pad_D1.0mm | ~
U1 | 1 | ATtiny1616-M |  |  |  | Package_DFN_QFN:VQFN-20-1EP_3x3mm_P0.4mm_EP1.7x1.7mm | http://ww1.microchip.com/downloads/en/DeviceDoc/ATtiny3216_ATtiny1616-data-sheet-40001997B.pdf

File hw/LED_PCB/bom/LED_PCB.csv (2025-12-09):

Reference | Qty | Value | DNP | Exclude from BOM | Exclude from Board | Footprint | Datasheet
C1,C2,C3,C4 | 4 | .1u |  |  |  | Capacitor_SMD:C_0603_1608Metric | ~
D1,D2,D3,D4,D5,D6,D7,D8,D9,D10 | 10 | APA102 |  |  |  | LED_SMD:LED_RGB_5050-6 | http://www.led-color.com/upload/201506/APA102%20LED.pdf
J1 | 1 | PPPC022LFBN-RC |  |  |  | Connector_PinSocket_2.54mm:PinSocket_2x02_P2.54mm_Vertical | ~

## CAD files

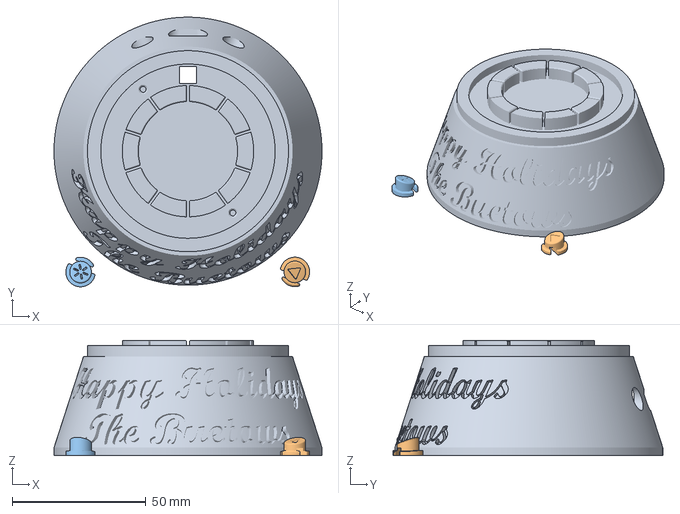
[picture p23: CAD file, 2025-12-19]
hw/Base/Base_core_one.3mf
100.0 x 100.6 x 43.0 mm
Base

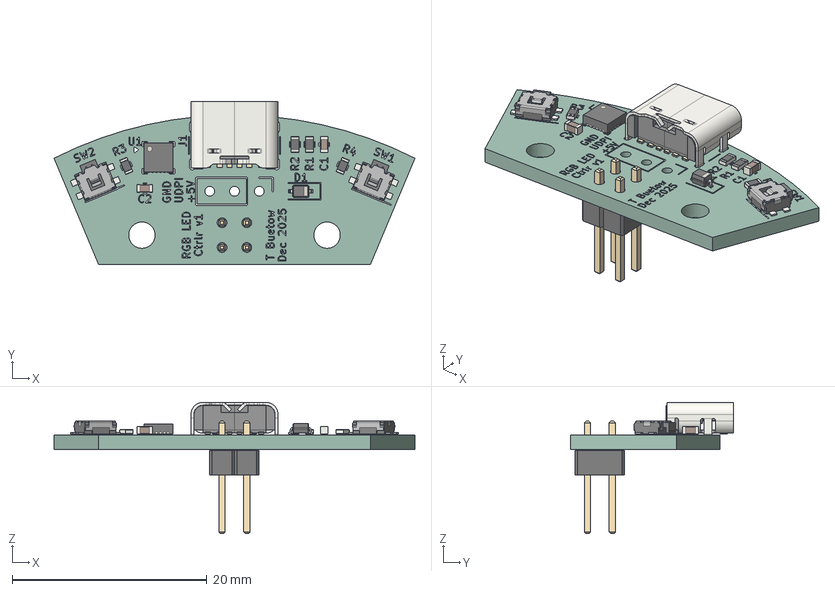
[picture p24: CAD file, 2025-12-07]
hw/Control_PCB/Control_PCB.step
37.0 x 16.7 x 13.5 mm
SW_SPST_EVQP7C x 2
QFN-24-1EP_3x3mm_P0.4mm_EP1.75x1.6mm
D_SOD-323
USB_C_Receptacle_GCT_USB4125-xx-x_6P_TopMnt_Horizontal
R_0603_1608Metric x 4
C_0603_1608Metric x 2
PinHeader_2x02_P2.54mm_Vertical
Control_PCB_silkscreen x 2
Control_PCB_PCB

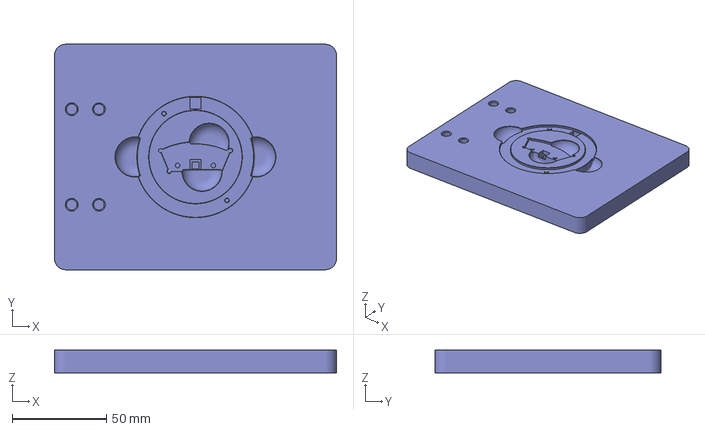
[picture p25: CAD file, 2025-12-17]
hw/Fixtures/Solder Fixture.3mf
150.0 x 120.0 x 12.0 mm

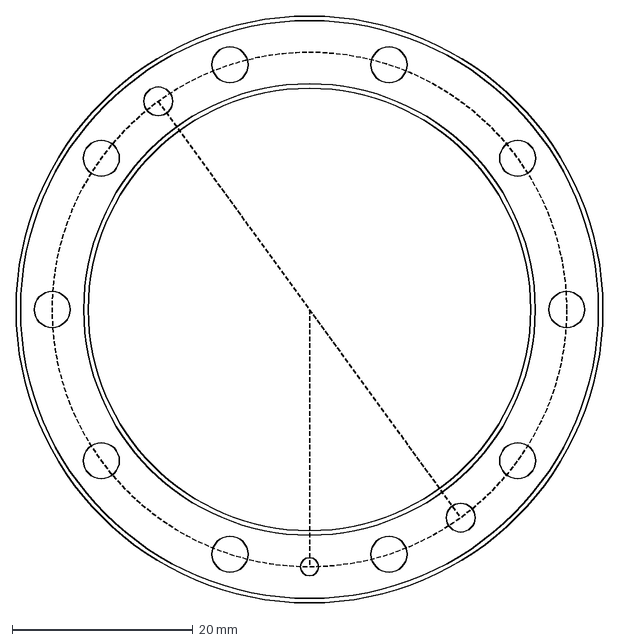
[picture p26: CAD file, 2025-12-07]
hw/LED_PCB/PCB OML.dxf
65.0 x 65.0 mm

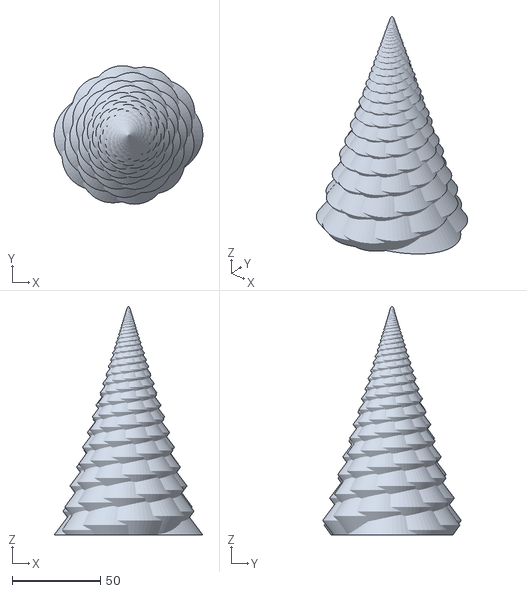
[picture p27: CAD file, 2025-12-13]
hw/Trees/Ultimate Vase Mode Christmas Tree Collection/Fibonacci spiral trees V2 3.stl
84.5 x 78.7 x 130.0

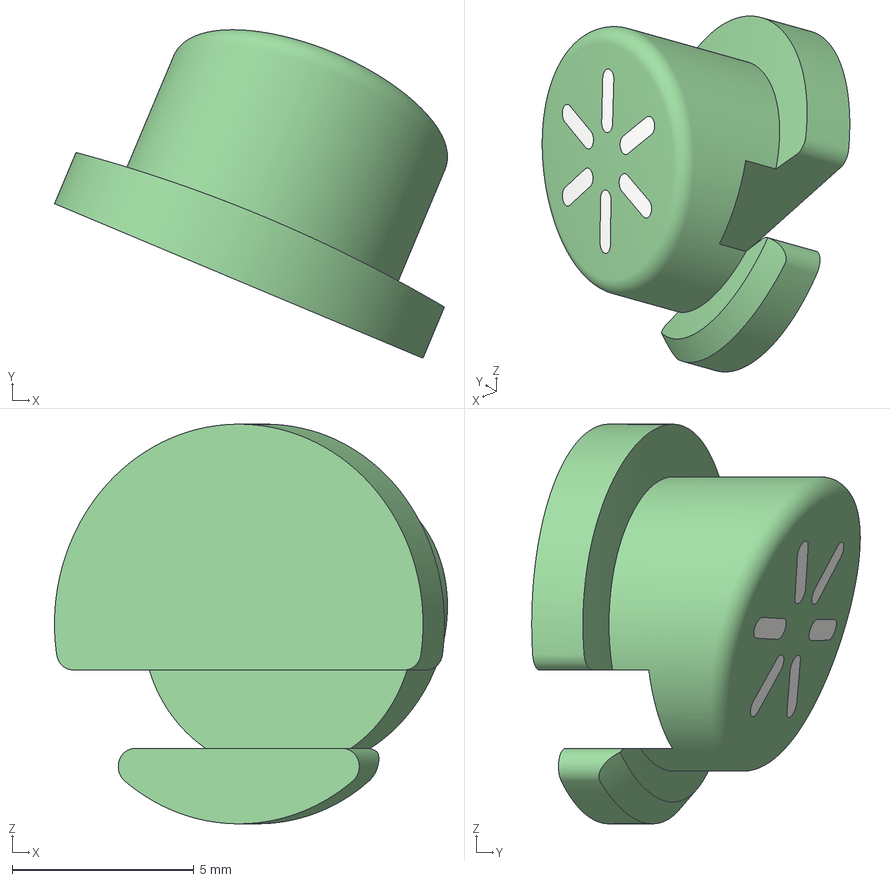
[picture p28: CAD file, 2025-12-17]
hw/Base/Button2.3mf
10.8 x 9.04 x 11.0 mm

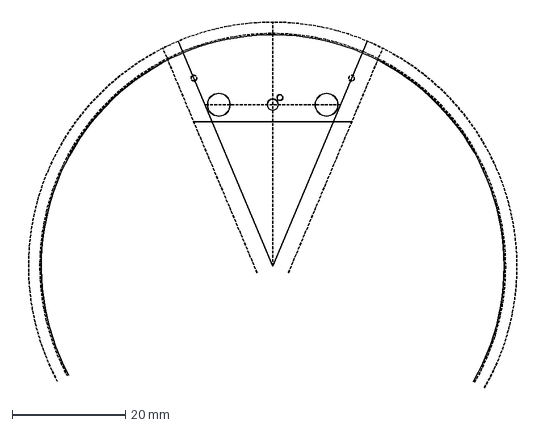
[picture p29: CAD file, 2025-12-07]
hw/Control_PCB/PCB OML.dxf
90.4 x 65.6 mm

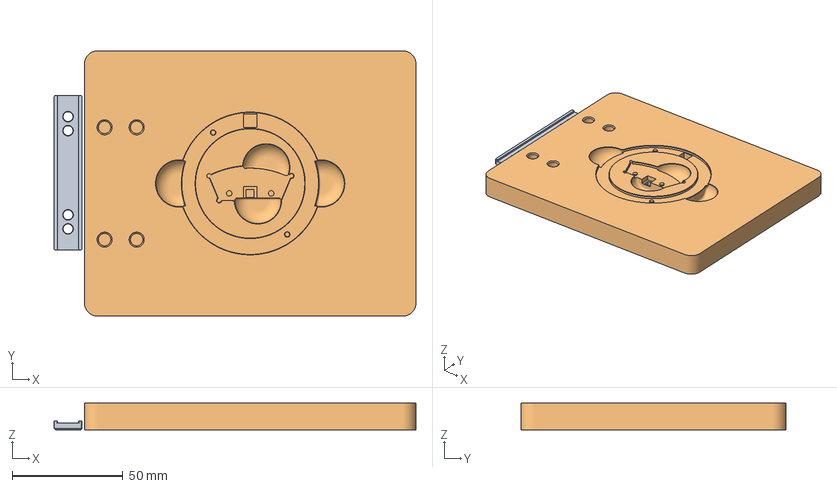
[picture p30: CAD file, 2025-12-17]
hw/Fixtures/Solder Fixture project.3mf
163.7 x 120.0 x 12.0 mm
clamp
Solder Fixture

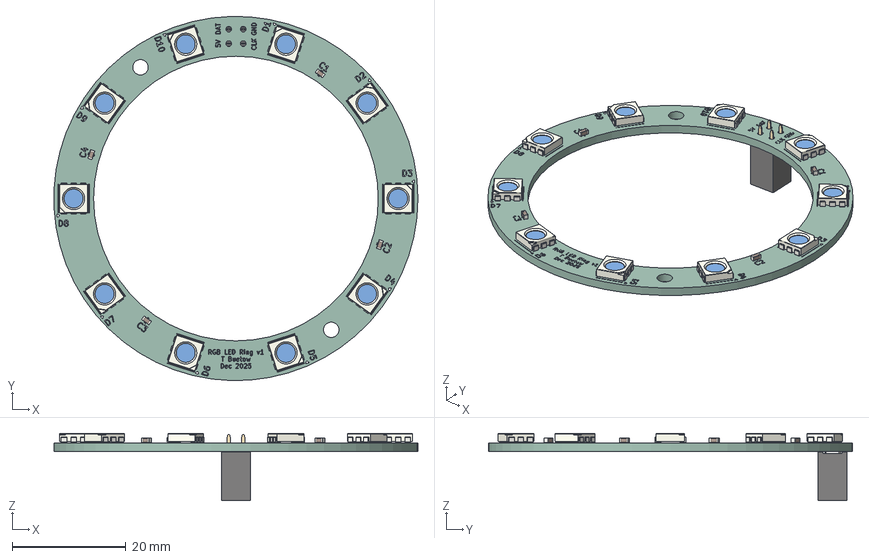
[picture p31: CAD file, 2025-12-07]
hw/LED_PCB/LED_PCB.step
63.9 x 64.0 x 11.8 mm
LED_RGB_5050-6 x 10
C_0603_1608Metric x 4
PinSocket_2x02_P2.54mm_Vertical
LED_PCB_silkscreen x 2
LED_PCB_PCB

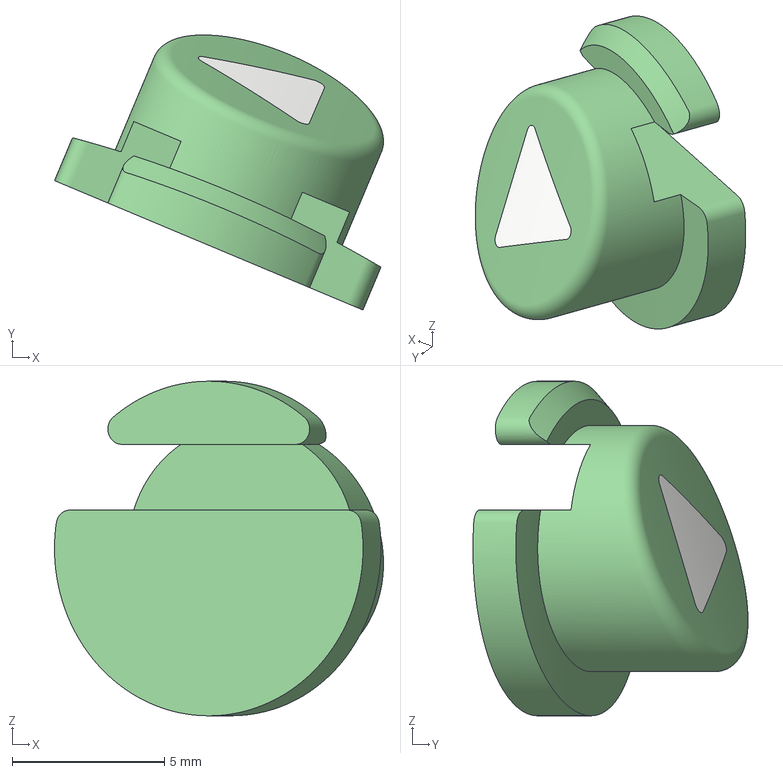
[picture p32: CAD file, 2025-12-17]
hw/Base/Button1.3mf
10.8 x 9.04 x 11.0 mm

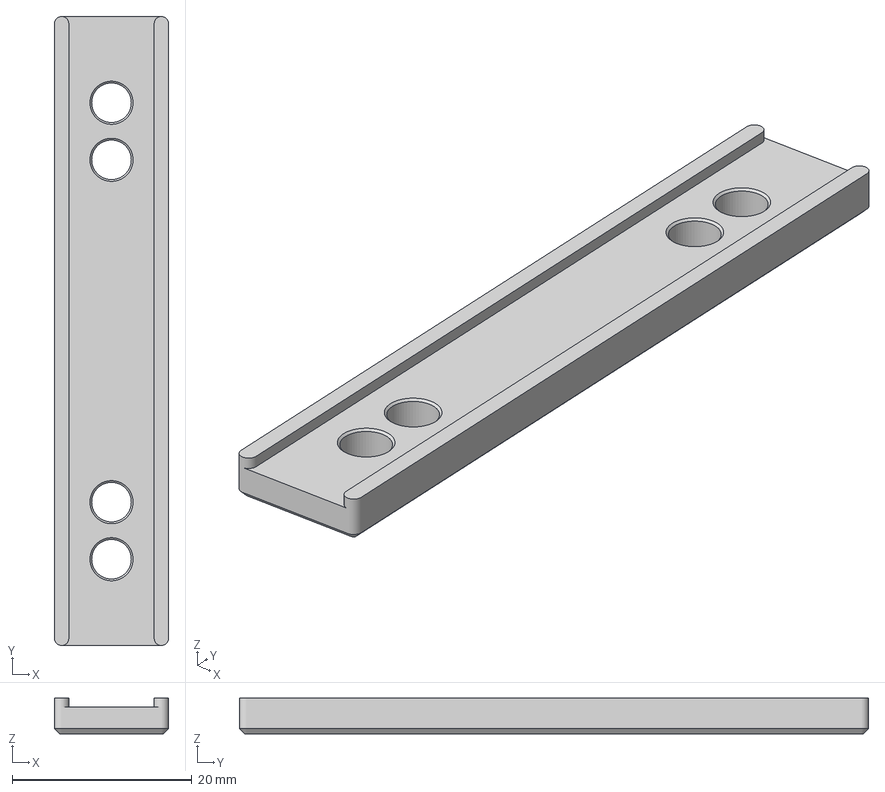
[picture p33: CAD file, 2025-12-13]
hw/Fixtures/clamp.3mf
12.7 x 70.0 x 4.00 mm

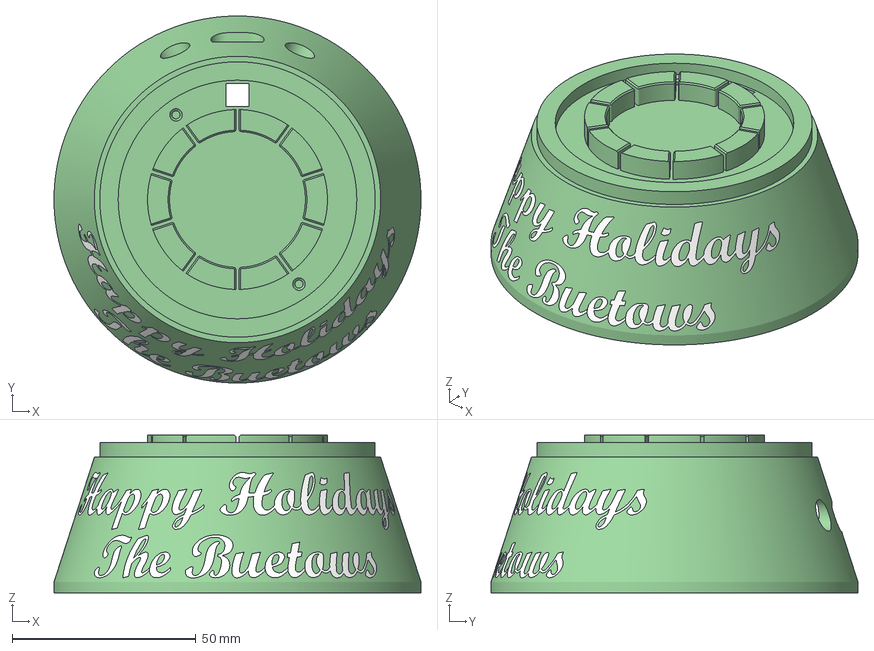
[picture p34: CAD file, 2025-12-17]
hw/Base/Base.3mf
100.0 x 100.0 x 43.0 mm
Base
text1
text10
text11
text12
text13
text14
text15
text16
text17
text2
text3
text4
text5
text6
text7
text8
text9

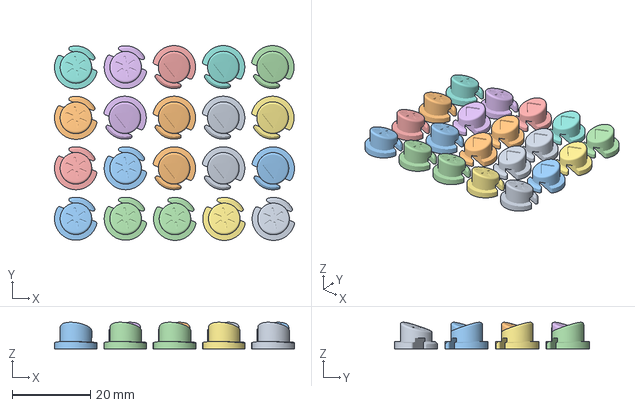
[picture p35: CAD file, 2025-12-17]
hw/Base/Buttons_core_one_.25mm.3mf
61.5 x 49.9 x 6.81 mm

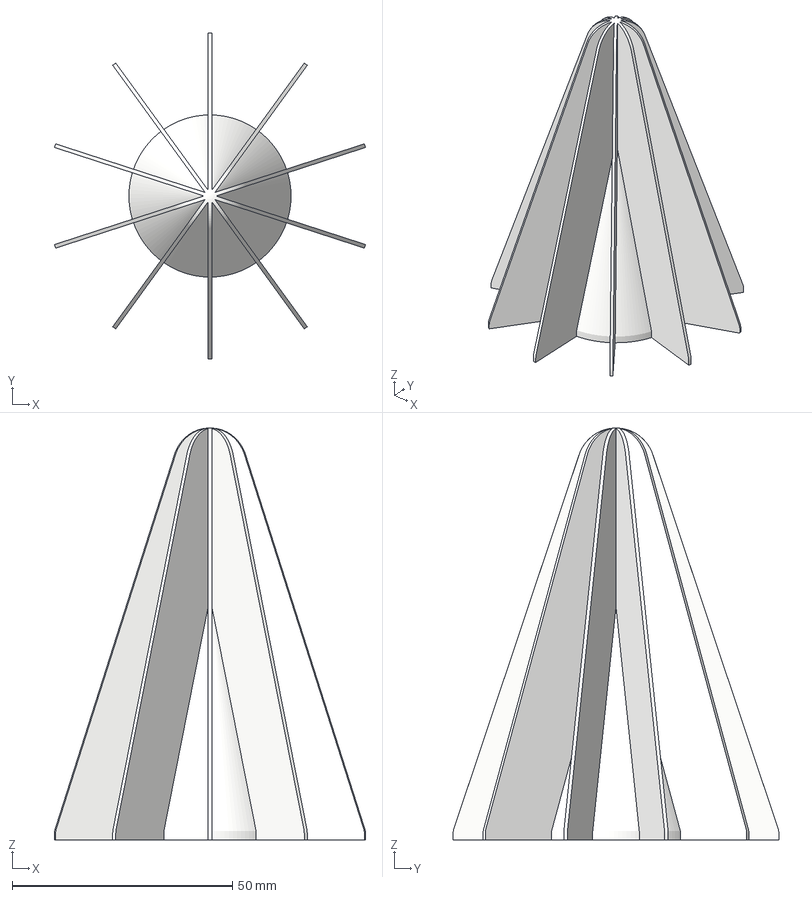
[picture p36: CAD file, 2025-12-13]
hw/Base/Light Partition.3mf
70.6 x 74.0 x 93.5 mm

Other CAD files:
hw/Base/Light Partition_core_one.3mf
hw/Base/Base_multimaterial_XL.3mf

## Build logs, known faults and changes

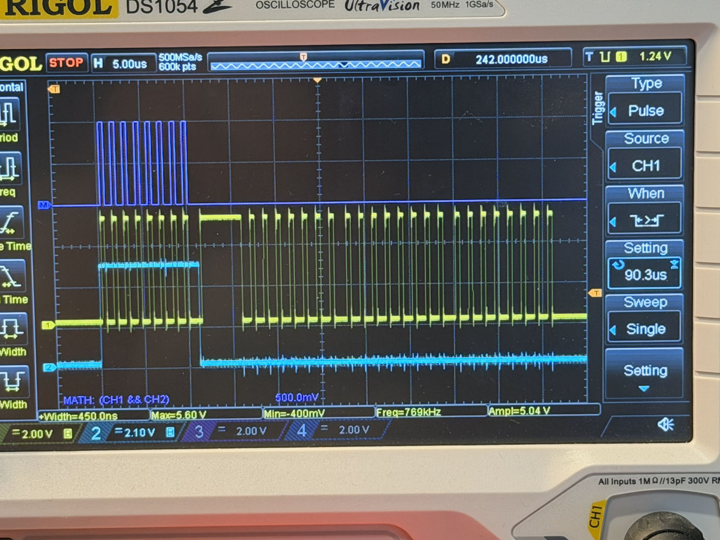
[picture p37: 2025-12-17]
images/debugging/ATtiny1616 APA102 Timing anomaly 2.jpg

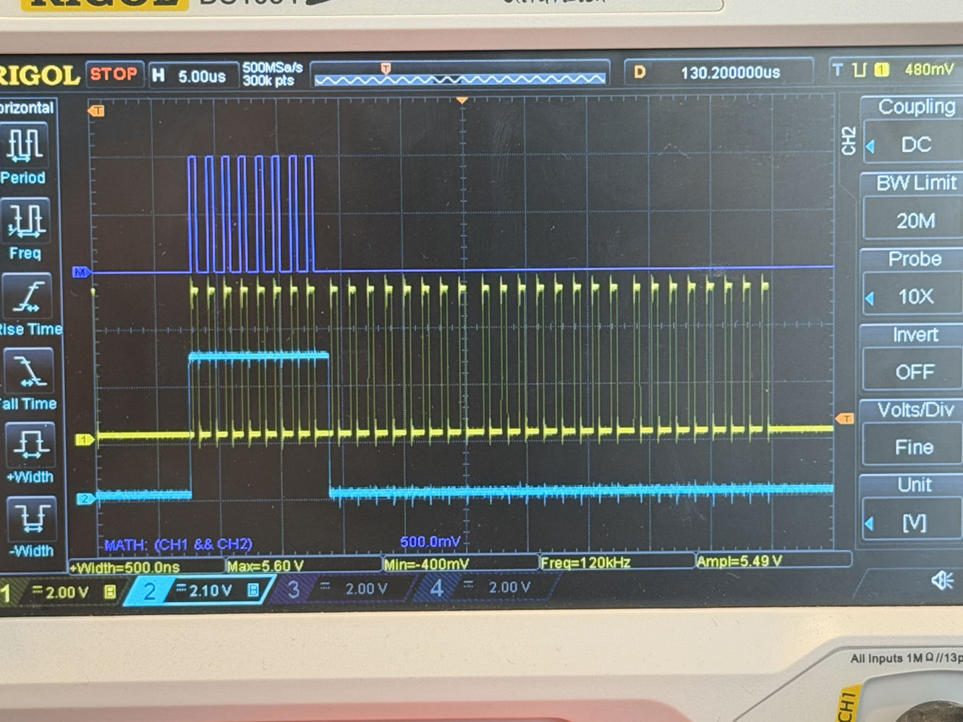
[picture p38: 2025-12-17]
images/debugging/ATtiny1616 Single Pixel APA102.jpg

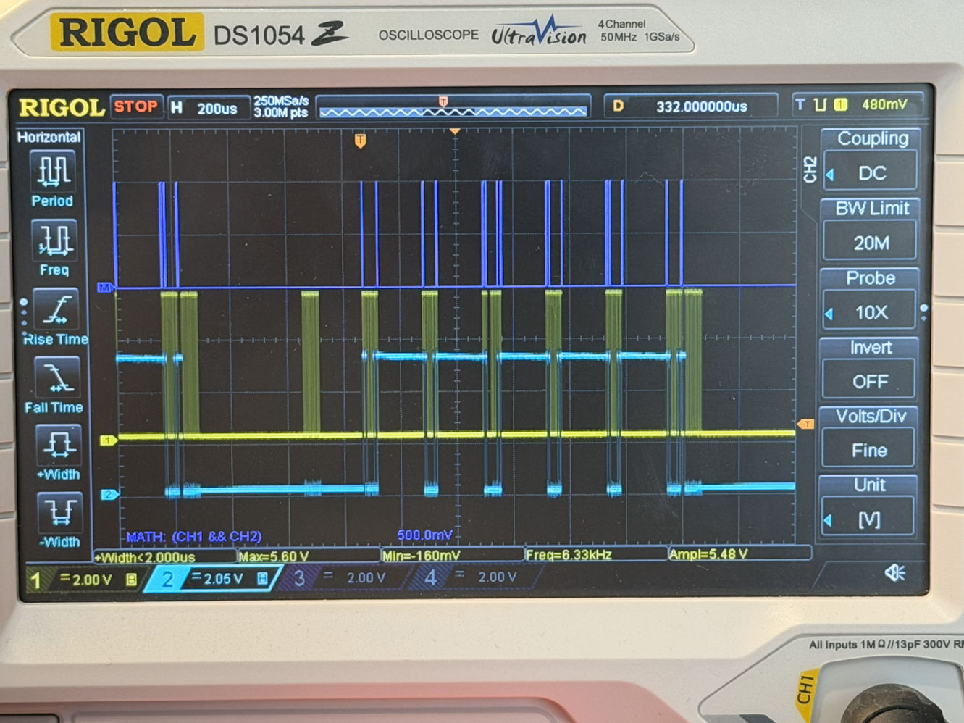
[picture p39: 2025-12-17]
images/debugging/ATtiny85 full APA102 Frame.jpg

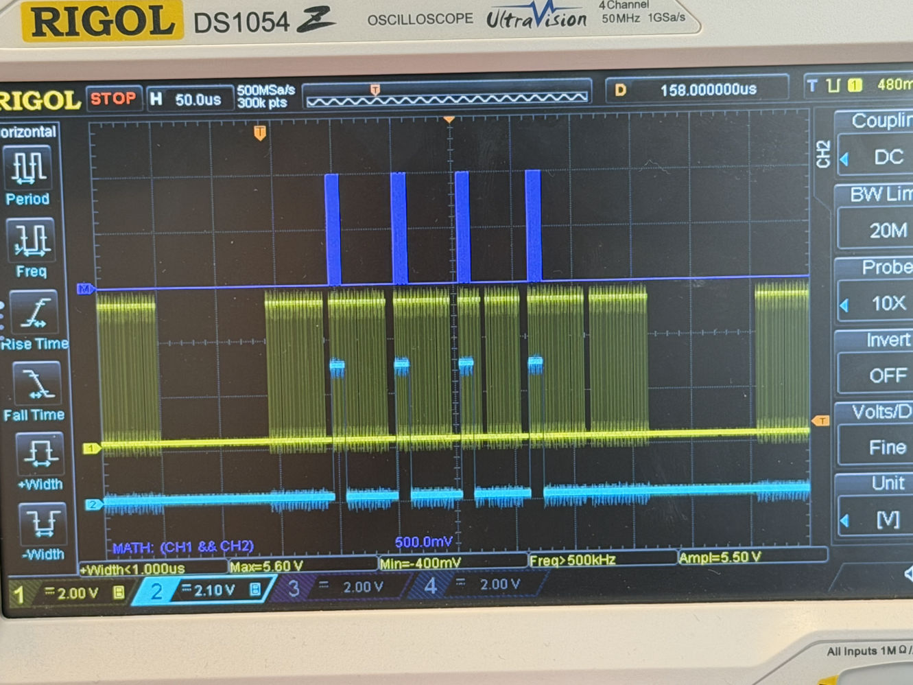
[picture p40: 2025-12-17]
images/debugging/ATtiny1616 full APA102 Frame.jpg

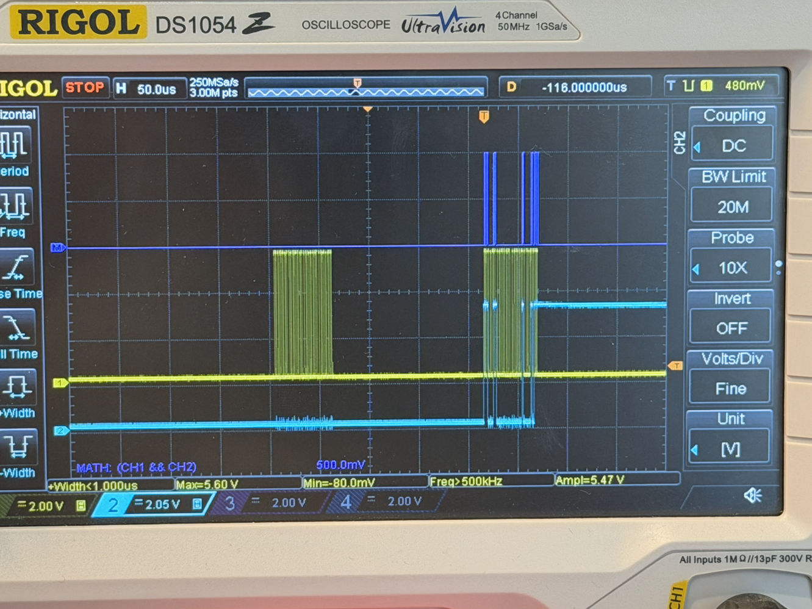
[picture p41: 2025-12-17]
images/debugging/ATtiny85 APA102 Start of Frame.jpg

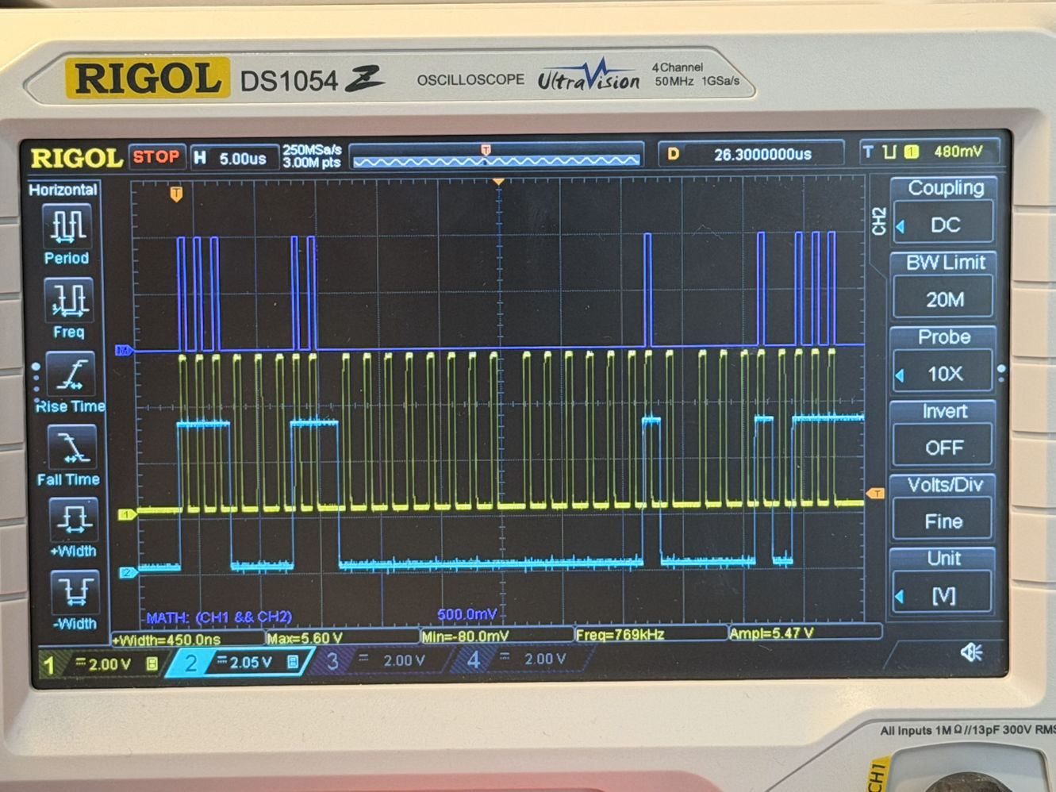
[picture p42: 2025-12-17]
images/debugging/ATtiny85 Single Pixel APA102.jpg

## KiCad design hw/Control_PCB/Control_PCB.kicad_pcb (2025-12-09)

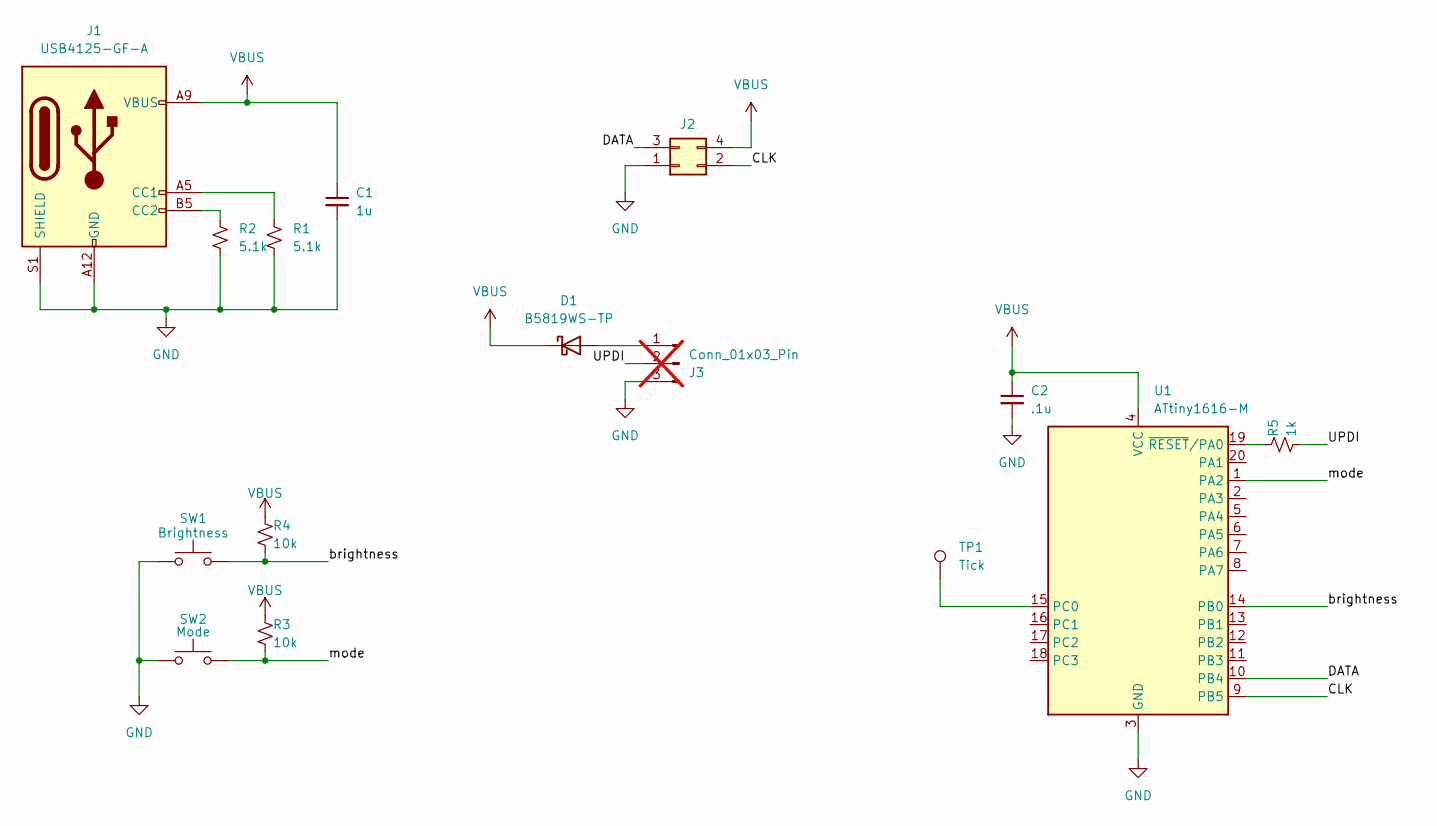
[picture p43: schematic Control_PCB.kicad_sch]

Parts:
C1: 1u; C_0603_1608Metric
C2: .1u; C_0603_1608Metric
D1: B5819WS-TP; D_SOD-323_HandSoldering
J1: USB4125-GF-A; USB_C_Receptacle_GCT_USB4125-xx-x_6P_TopMnt_Horizontal
J2: PRPC040DAAN-RC; PinHeader_2x02_P2.54mm_Vertical
J3: Conn_01x03_Pin; PinHeader_1x03_P2.54mm_Vertical; not fitted
R1, R2: 5.1k; R_0603_1608Metric
R3, R4: 10k; R_0603_1608Metric
R5: 1k; R_0603_1608Metric
SW1: Brightness; SW_SPST_EVQP7C
SW2: Mode; SW_SPST_EVQP7C
TP1: Tick; TestPoint_Pad_D1.0mm
U1: ATtiny1616-M; VQFN-20-1EP_3x3mm_P0.4mm_EP1.7x1.7mm

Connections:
/CLK: J2.2, U1.9 (PB5)
/DATA: J2.3, U1.10 (PB4)
/UPDI: J3.2, R5.2
/brightness: R4.2, SW1.2, U1.14 (PB0)
/mode: R3.2, SW2.2, U1.1 (PA2)
GND: C1.2, C2.2, J1.A12 (GND), J1.B12 (GND), J1.S1 (SHIELD), J2.1, J3.3, R1.2, R2.2, SW1.1, SW2.1, U1.3 (GND), U1.21 (GND)
unnamed: D1.2 (A), J3.1
unnamed: J1.A5 (CC1), R1.1
unnamed: J1.B5 (CC2), R2.1
unnamed: TP1.1, U1.15 (PC0)
unnamed: R5.1, U1.19 (~RESET/PA0)
VBUS: C1.1, C2.1, D1.1 (K), J1.A9 (VBUS), J1.B9 (VBUS), J2.4, R3.1, R4.1, U1.4 (VCC)

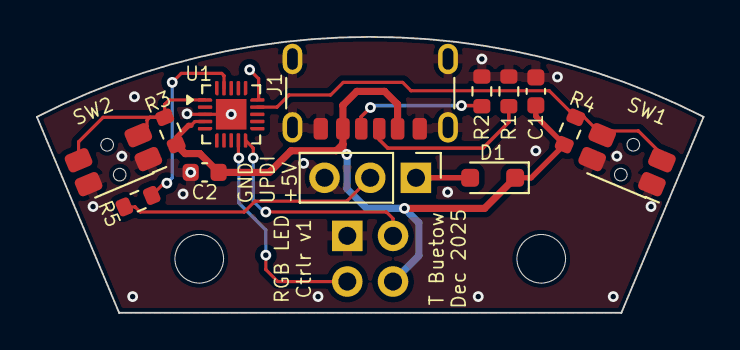
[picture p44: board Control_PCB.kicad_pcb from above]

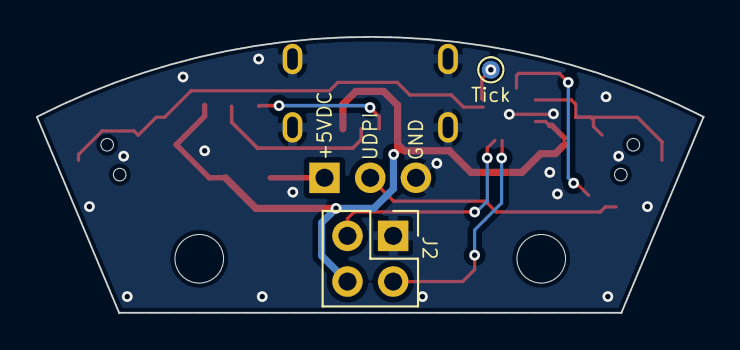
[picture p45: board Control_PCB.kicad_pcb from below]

Board: 2 copper layers, 37.0 x 15.3 mm, 15 parts (2 on the bottom side), 12 nets.

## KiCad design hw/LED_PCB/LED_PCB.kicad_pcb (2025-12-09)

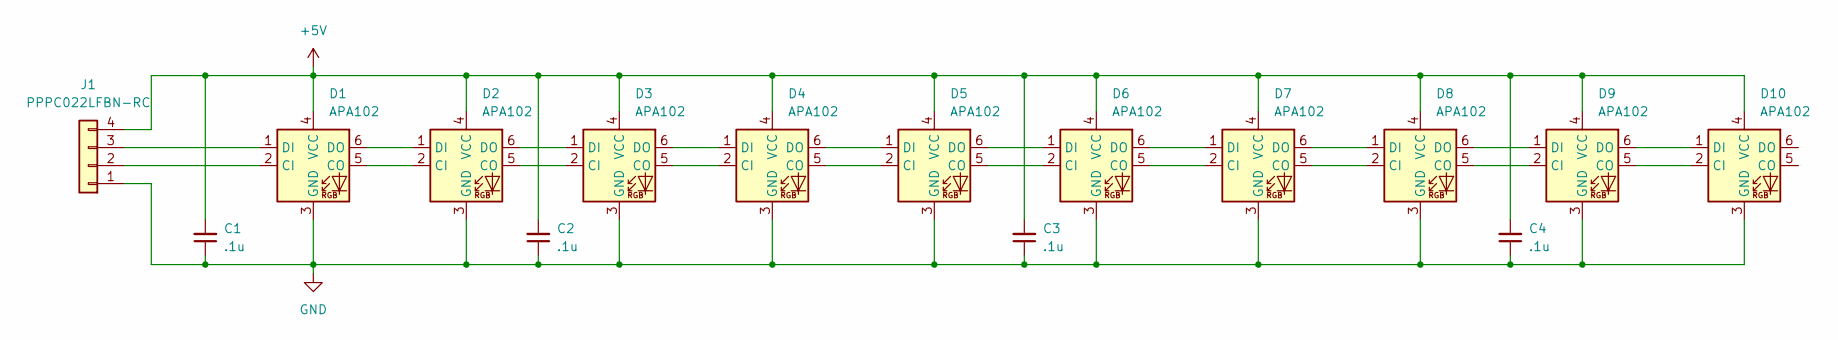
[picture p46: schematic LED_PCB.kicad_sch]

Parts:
C1, C2, C3, C4: .1u; C_0603_1608Metric
D1, D2, D3, D4, D5, D6, D7, D8, D9, D10: APA102; LED_RGB_5050-6
J1: PPPC022LFBN-RC; PinSocket_2x02_P2.54mm_Vertical

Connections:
+5V: C1.2, C2.2, C3.2, C4.2, D1.4 (VCC), D2.4 (VCC), D3.4 (VCC), D4.4 (VCC), D5.4 (VCC), D6.4 (VCC), D7.4 (VCC), D8.4 (VCC), D9.4 (VCC), D10.4 (VCC), J1.4
GND: C1.1, C2.1, C3.1, C4.1, D1.3 (GND), D2.3 (GND), D3.3 (GND), D4.3 (GND), D5.3 (GND), D6.3 (GND), D7.3 (GND), D8.3 (GND), D9.3 (GND), D10.3 (GND), J1.1
unnamed: D1.2 (CI), J1.2
unnamed: D1.5 (CO), D2.2 (CI)
unnamed: D1.1 (DI), J1.3
unnamed: D1.6 (DO), D2.1 (DI)
unnamed: D2.5 (CO), D3.2 (CI)
unnamed: D2.6 (DO), D3.1 (DI)
unnamed: D3.5 (CO), D4.2 (CI)
unnamed: D3.6 (DO), D4.1 (DI)
unnamed: D4.5 (CO), D5.2 (CI)
unnamed: D4.6 (DO), D5.1 (DI)
unnamed: D5.5 (CO), D6.2 (CI)
unnamed: D5.6 (DO), D6.1 (DI)
unnamed: D6.5 (CO), D7.2 (CI)
unnamed: D6.6 (DO), D7.1 (DI)
unnamed: D7.5 (CO), D8.2 (CI)
unnamed: D7.6 (DO), D8.1 (DI)
unnamed: D8.5 (CO), D9.2 (CI)
unnamed: D8.6 (DO), D9.1 (DI)
unnamed: D9.5 (CO), D10.2 (CI)
unnamed: D9.6 (DO), D10.1 (DI)

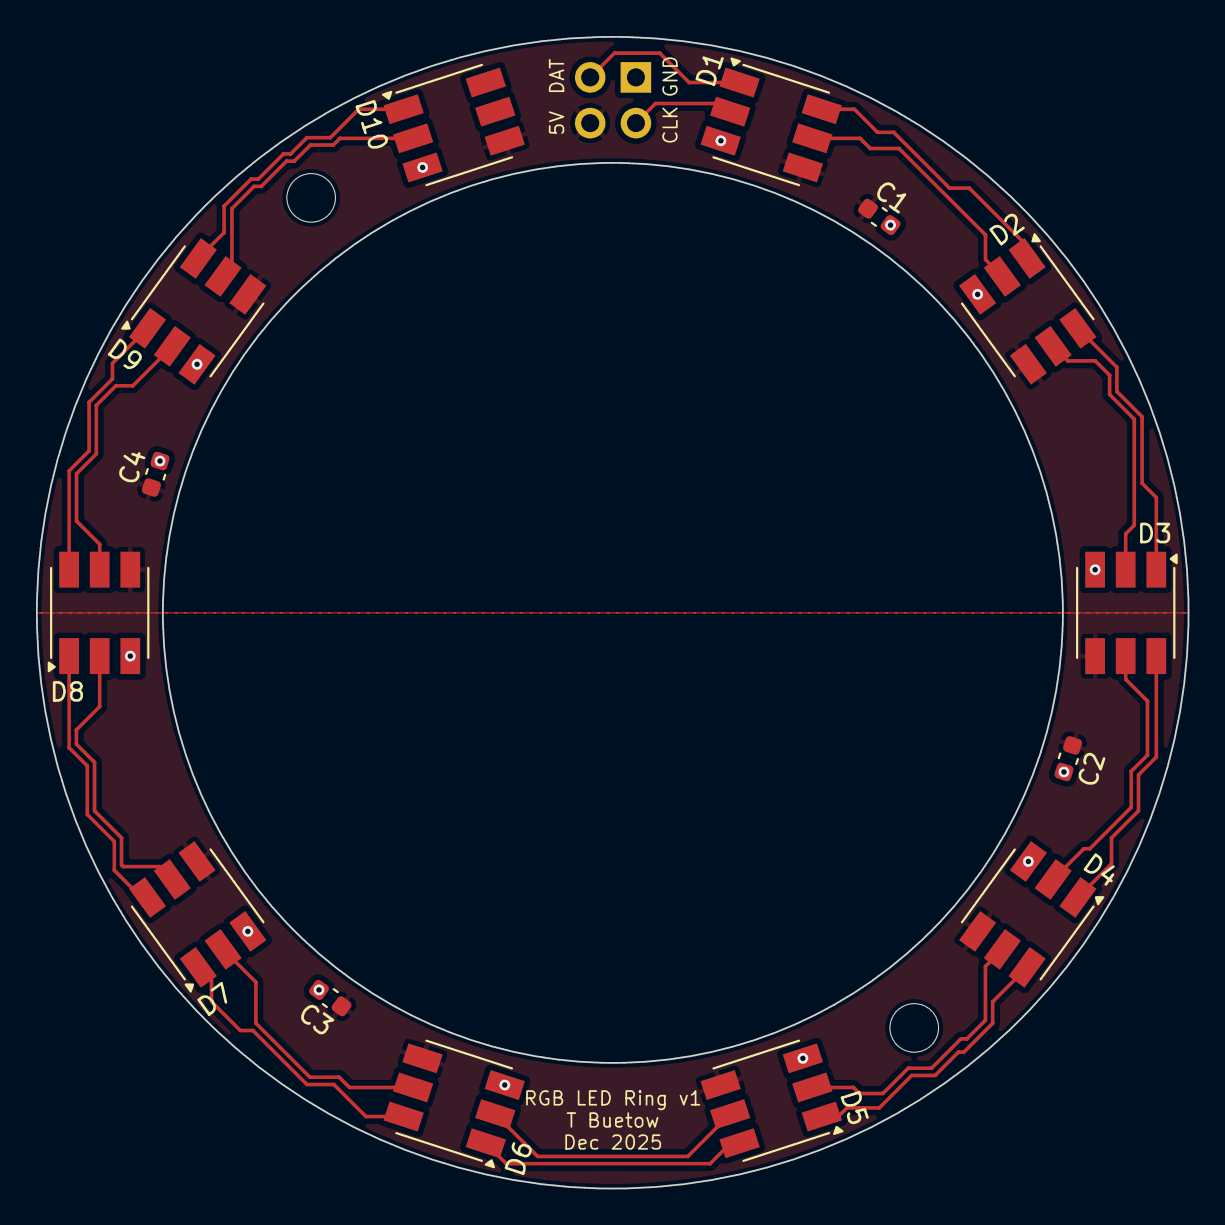
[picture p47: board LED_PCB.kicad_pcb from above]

Board: 2 copper layers, 64.0 x 64.0 mm, 15 parts (1 on the bottom side), 22 nets.

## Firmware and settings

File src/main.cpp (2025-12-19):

/*
  main.c RGB LED Effects for addressable LEDs. Allows for changing of effects and brightness with buttons.
*/
#include <FastLED.h>
#include <Arduino.h>
#include <stdint.h>
#include <EEPROM.h>
#include "button.h"
#include "config.h"
#include "hardware.h"
#include "state.h"


CRGB leds[Config::NUM_LEDS];
constexpr uint16_t RAINBOW_STEPS = 256;
constexpr uint32_t RAINBOW_SLOW_STEP_MS = (Config::CYCLE_TIME_SECONDS_SLOW * 1000UL) / RAINBOW_STEPS;
constexpr uint32_t RAINBOW_FAST_STEP_MS = (Config::CYCLE_TIME_SECONDS_FAST * 1000UL) / RAINBOW_STEPS;


constexpr uint8_t PARADE_STEP_MS = (Config::PARADE_CYCLE_TIME_SECONDS * 1000UL) / RAINBOW_STEPS;
constexpr uint8_t TWINKLE_STEP_MS = 16;
constexpr uint8_t TWINKLE_PEAK = 220;
constexpr uint8_t TWINKLE_UP_STEP = TWINKLE_PEAK / (Config::TWINKLE_RISE_TIME_MS / TWINKLE_STEP_MS);
constexpr uint8_t TWINKLE_DOWN_STEP = TWINKLE_PEAK / (Config::TWINKLE_FALL_TIME_MS / TWINKLE_STEP_MS);
constexpr uint8_t TWINKLE_REST_STEP = TWINKLE_PEAK / (Config::TWINKLE_REST_TIME_MS / TWINKLE_STEP_MS);

constexpr uint8_t NOISE_STEP_MS = 16;
constexpr uint8_t MIDPOINT = 127;

uint8_t twinkleValue[Config::NUM_LEDS];
bool twinkleRising[Config::NUM_LEDS];
uint8_t twinkleRest[Config::NUM_LEDS];

uint8_t hue_val = 0;
uint8_t parade_phase = 0;
uint16_t holidayNoiseZ = 0;


uint8_t dim_white_to_color(uint8_t color_sat_val) {
  //value scaling here (and elsewhere) does a good job of matching the apparent brightness of white to the color (hue=23).
  return 175 + scale8(cubicwave8(color_sat_val),80);
}

CRGB holidayNoiseColor(uint8_t noiseVal) {
  const CRGB red = CHSV(Config::RED_HUE, 255, 255);
  const CRGB green = CHSV(Config::GREEN_HUE, 255, 255);
  const CRGB white = CHSV(0, 0, 200);

  const uint8_t lowerBlendStart = MIDPOINT - Config::BLEND_DISTANCE; // e.g. 27 when BLEND_DISTANCE=100
  const uint8_t upperBlendEnd   = MIDPOINT + Config::BLEND_DISTANCE; // clamp handled by uint8 wrap avoidance

  if (noiseVal <= lowerBlendStart) {
    return red; // 0..lowerBlendStart
  }
  if (noiseVal <= MIDPOINT) {
    // lowerBlendStart..MIDPOINT: red -> white
    uint8_t range = MIDPOINT - lowerBlendStart;
    uint8_t mix = ((uint16_t)(noiseVal - lowerBlendStart) * 255) / range;
    return blend(red, white, mix);
  }
  if (noiseVal <= upperBlendEnd) {
    // MIDPOINT..upperBlendEnd: white -> green
    uint8_t range = upperBlendEnd - MIDPOINT;
    uint8_t mix = ((uint16_t)(noiseVal - MIDPOINT) * 255) / range;
    return blend(white, green, mix);
  }
  return green; // above upperBlendEnd
}

void updateTwinkles(uint8_t baseHue) {
  for (uint8_t i = 0; i < Config::NUM_LEDS; i++) {
    // Decide if a new twinkle should start
    if (!twinkleRising[i] && twinkleValue[i] == 0 && twinkleRest[i] == 0 && random8(100) < Config::TWINKLE_CHANCE) {
      twinkleRising[i] = true;
      twinkleRest[i] = TWINKLE_PEAK;
    }

    if (twinkleRising[i]) {
      twinkleValue[i] = qadd8(twinkleValue[i], TWINKLE_UP_STEP);
      if (twinkleValue[i] >= TWINKLE_PEAK) {
        twinkleValue[i] = TWINKLE_PEAK;
        twinkleRising[i] = false;
      }
    } else if (twinkleValue[i] > 0) {
      twinkleValue[i] = qsub8(twinkleValue[i], TWINKLE_DOWN_STEP);
    } else {
      twinkleRest[i] = qsub8(twinkleRest[i],TWINKLE_REST_STEP);
    }

    CRGB base = CHSV(baseHue, 255, 200);
    leds[i] = base + CHSV(0, 0, twinkleValue[i]);
  }
}


void setup () {
  init_CPU();
  init_gpio();
  delay(50);
  load_state();

  delay(100);
  FastLED.addLeds<APA102, Config::DATA_PIN, Config::CLK_PIN, Config::LED_COLOR_ORDER>(leds, Config::NUM_LEDS);
  FastLED.setCorrection(TypicalSMD5050);
  FastLED.setTemperature(UncorrectedTemperature);
}

void loop() {
  
  while(1) {
    Mode mode = current_mode();
    static Mode prevMode = mode;
    if (mode != prevMode) {
      for (uint8_t i = 0; i < Config::NUM_LEDS; i++) {
        twinkleValue[i] = 0;
        twinkleRising[i] = false;
        twinkleRest[i] = 0;
      }
      fill_solid(leds, Config::NUM_LEDS, CRGB::Black);
      prevMode = mode;
    }

    EVERY_N_MILLIS_I(buttonPollTimer, Config::BUTTON_SAMPLE_MS) { service_buttons(); }

    switch (mode)
    {
    case Mode::RAINBOW_SOLID_SLOW: //Slowly fade all leds toghether around the rainbow
      EVERY_N_MILLIS_I(rainbowSolidSlowTimer, RAINBOW_SLOW_STEP_MS) {
        fill_solid(leds, Config::NUM_LEDS, CHSV(hue_val++, 255, 255));
      }
      break;

    case Mode::RAINBOW_SOLID_FAST: //Quickly fade all leds toghether around the rainbow
      EVERY_N_MILLIS_I(rainbowSolidFastTimer, RAINBOW_FAST_STEP_MS) {
        fill_solid(leds, Config::NUM_LEDS, CHSV(hue_val++, 255, 255));
      }
      break;

    case Mode::RAINBOW_WAVE_FAST: //Quickly fade all leds through the rainbow. The rainbow also fades one complete hue cycle across the LEDs
      EVERY_N_MILLIS_I(rainbowWaveFastTimer, RAINBOW_FAST_STEP_MS) {
        for(uint8_t i = 0; i < Config::NUM_LEDS; i++) {
          leds[i] = CHSV(hue_val - i*255/(Config::NUM_LEDS), 255, 255);
        }
        hue_val++;
      }
      break;

    case Mode::GREEN_WHITE_PARADE: //LEDs fading between colors, marching around the circle
    case Mode::RED_WHITE_PARADE:
    case Mode::GREEN_RED_PARADE:
      EVERY_N_MILLIS_I(colorWhiteParadeTimer, PARADE_STEP_MS) {
        parade_phase = (parade_phase + 1) % 255;
      }
      for (uint8_t i = 0; i < Config::NUM_LEDS; i++) {
        uint8_t t = parade_phase; // controls speed

        const uint8_t width = 5;
        uint8_t pos_color = (i * (256 / width)) - t; //order of ops matters for overflow - saves on using 16 bit math.
        uint8_t pos_white = (i * (256 / width)) - t - 128;

        uint8_t bright_color = cubicwave8(pos_color);
        uint8_t bright_white = cubicwave8(pos_white);
        if (current_mode() == Mode::GREEN_WHITE_PARADE){
          leds[i] = CHSV(Config::GREEN_HUE, 255, bright_color) + CHSV(Config::GREEN_HUE, 0, scale8(bright_white,200));
        } else if (current_mode() == Mode::RED_WHITE_PARADE) {
          leds[i] = CHSV(Config::RED_HUE, 255, bright_color) + CHSV(Config::RED_HUE, 0, scale8(bright_white,200));
        } else {
          leds[i] = CHSV(Config::RED_HUE, 255, bright_color) + CHSV(Config::GREEN_HUE, 255, bright_white);
        }
      }
      break;

    case Mode::TWINKLE_RED:
    case Mode::TWINKLE_GREEN:
      EVERY_N_MILLIS_I(twinkleTimer, TWINKLE_STEP_MS) {
        updateTwinkles(mode == Mode::TWINKLE_RED ? Config::RED_HUE : Config::GREEN_HUE);
      }
      break;

    case Mode::HOLIDAY_NOISE:
      EVERY_N_MILLIS_I(noiseTimer, NOISE_STEP_MS) {
        holidayNoiseZ += Config::NOISE_Z_STEP;
        for (uint8_t i = 0; i < Config::NUM_LEDS; i++) {
          uint16_t x = i * Config::NOISE_SAMPLE_DISTANCE;
          uint8_t noiseVal = inoise8(x, holidayNoiseZ);
          leds[i] = holidayNoiseColor(noiseVal);
        }
      }
      break;

    case Mode::SOLID_RED:
      fill_solid(leds,Config::NUM_LEDS,CHSV(Config::RED_HUE,255,255));
      break;
      
    case Mode::SOLID_GREEN: //LEDs are static color
      fill_solid(leds,Config::NUM_LEDS,CHSV(Config::GREEN_HUE,255,255));
      break;

    case Mode::SOLID_WHITE: //LEDs are white
      fill_solid(leds,Config::NUM_LEDS,CHSV(0,0,200));
      break;

  default:
      break;
    }
    FastLED.setBrightness(gamma_corrected_brightness());
    VPORTC.OUT |= (1 << Config::TICK_OUT_BIT); //rising edge on start of LED write out
    FastLED.show();  // Update LEDs. Want to run this as often as possible.
    VPORTC.OUT &= ~(1 << Config::TICK_OUT_BIT); // pulse width = led write time, period = loop time
    save_state_if_needed();

    // VPORTC.OUT ^= (1 << TICK_OUT); //toggle the TICK_OUT pin for hardware debugging purposes
  }
}

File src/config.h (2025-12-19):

#pragma once
#include <stdint.h>
#include <FastLED.h>

namespace Config {

// PATTERN CONTROL //
//Rainbow Cycles
constexpr uint16_t CYCLE_TIME_SECONDS_SLOW = 300; 
constexpr uint8_t CYCLE_TIME_SECONDS_FAST = 10; //also used for rainbow wave

//Parade Cycles
constexpr uint8_t PARADE_CYCLE_TIME_SECONDS = 2;

//Twinkles
constexpr uint16_t TWINKLE_RISE_TIME_MS = 75;
constexpr uint16_t TWINKLE_FALL_TIME_MS = 1300;
constexpr uint16_t TWINKLE_REST_TIME_MS = 1500;
constexpr uint8_t TWINKLE_CHANCE = 1; // percent chance every cycle time

//Noise
constexpr uint8_t BLEND_DISTANCE = 50; // value 0 - 127 from which to stop blending in white and become solid.
constexpr uint8_t NOISE_SAMPLE_DISTANCE = 40; // "distance" between each LED on the 1-D noise map. Farther distances make each LED more independent.
constexpr uint8_t NOISE_Z_STEP = 2; // "time" axis to move perlin noise in 2D map with each step. Larger steps make the pattern move faster.

//Solid colors
constexpr uint8_t GREEN_HUE = 97; // Green - scaled to 0..255 instead of 0..360deg
constexpr uint8_t RED_HUE = 0; // Red - scaled to 0..255 instead of 0..360deg


// HARDWARE CONFIG //
constexpr uint8_t DATA_PIN = PIN_PB4;          // Physical PB4
constexpr uint8_t CLK_PIN = PIN_PB5;           // Physical PB5
constexpr uint8_t TICK_OUT_BIT = PIN0_bp;      // Physical PC0, accessed through VPORTC
constexpr uint8_t BRIGHTNESS_BUTTON_BIT = PIN0_bp; // Physical PB0
constexpr uint8_t MODE_BUTTON_BIT = PIN2_bp;        // Physical PA2
constexpr uint8_t NUM_LEDS = 10; //Number of LEDS on the board
constexpr fl::EOrder LED_COLOR_ORDER = BGR; //RBG usually for adafruit, BGR usually for Aliexpress vendor COCurve 
constexpr uint8_t EEPROM_ADDR_BRIGHTNESS = 0x01;
constexpr uint8_t EEPROM_ADDR_MODE = 0x02;


// BRIGHTNESS and MODES //
constexpr uint8_t BRIGHTNESS_STEPS = 4; //Number of steps to divide min 50 and max 255 into.
constexpr uint8_t BUTTON_SAMPLE_MS = 10;


} // namespace Config

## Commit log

2025-12-07 Initial hardware designs. PCBs ready for final review.
    [Base.3mf, Base_core_one.3mf, Base_multimaterial_XL.3mf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]
2025-12-09 PCB release to manufacturing
    [Control_PCB-B_Cu.gbr, Control_PCB-B_Mask.gbr, Control_PCB-B_Paste.gbr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]
2025-12-09 BOM complete
    [Control_PCB.csv, Control_PCB.kicad_pcb, Control_PCB.kicad_sch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]
2025-12-13 Base ready to begin printing
    [Base.3mf, Base_core_one.3mf, Button1.3mf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]
2025-12-13 Created complete BOM
    [Overall Bill of Materials.xlsx]
2025-12-13 Tree files and projects with README and licenses.
    [Fibonacci spiral trees V2 3.stl]
2025-12-13 Add clamp to solder fixture
    [Solder Fixture v4 project.3mf, clamp.3mf]
2025-12-15 Remove some static effects, excise remaining #define, config at top for LED color order.
2025-12-17 Remove APA102HD - does not work with ATtiny1616 for some reason.
    [main.cpp]
2025-12-17 Reworked timers, button servicing. Reduce files - move input (just button servicing) to hardware.
    [config.h, main.cpp]
2025-12-17 Projection changes based on trying to install buttons.
    [Base.3mf, Button1.3mf, Button2.3mf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]
2025-12-17 Change UPDI buffer resistor to 0 Ohms. Internet recommendation of 1k didn't work. Not sure this is needed because of diode on UPDI 5V rail.
    [Control_PCB.kicad_sch, Overall Bill of Materials.xlsx]
2025-12-17 Update solder screen fixture based on first useage. Make it easier to remove boards.
    [Solder Fixture project.3mf, Solder Fixture v4 project.3mf, Solder Fixture.3mf]
2025-12-19 New effects largely in place. Still need to tune perlin noise and twinkling.
    [config.h, main.cpp]
2025-12-19 More twinkle tuning. Added rest timer.
2025-12-19 noise blending better. Issue with red flickering still to solve.
    [config.h, main.cpp]
2025-12-19 Working noise! All parameters tuned enough to make me happy.
    [config.h, main.cpp]
2025-12-19 Further manufacturing updates - 3mf projects now contain latest version of base.
    [Base_core_one.3mf]
2025-12-19 Much better understanding of perlin noise - added adjustable 1D distance parameter.
    [config.h, main.cpp]
